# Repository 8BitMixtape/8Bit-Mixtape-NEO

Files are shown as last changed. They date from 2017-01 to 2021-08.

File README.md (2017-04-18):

# 8Bit Mixtape NEO
New Attiny85 based edition with Bootloader to program it via sound.

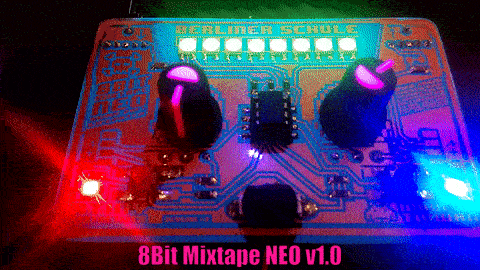
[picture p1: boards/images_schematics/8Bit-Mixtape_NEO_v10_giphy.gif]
Working v10_taipei


## Documentation and Instructions

It's all on the wiki...

## Arduino IDE-Integration

Add this to your additional hardware manager: http://8bitmixtape.github.io/package_8bitmixtape_index.json

See more on:  https://github.com/8BitMixtape/8Bit-Mixtape-NEO/wiki/4_3-IDE-integration

## Web-Interface

Upload examples directly from the browser: https://8bitmixtape.github.io/

Convert hex2Wav in browser and talk to your synth: https://8bitmixtape.github.io/8Bit-Mixtape-NEO/webpage/

## First Working prototypes

### Self-etched "Made in Taiwan"

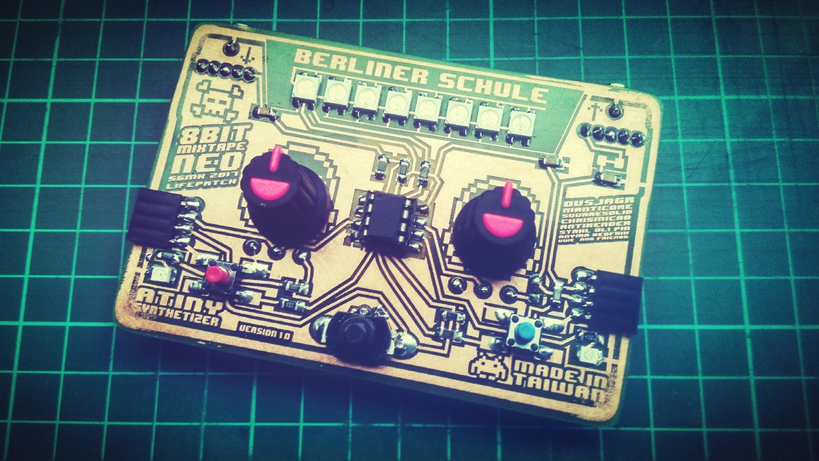
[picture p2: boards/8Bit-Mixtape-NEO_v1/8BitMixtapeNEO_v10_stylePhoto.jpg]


### Tokyo hand-solderer Prototype

See our first working prototype in the video: https://www.youtube.com/watch?v=9HnzJeK31R8

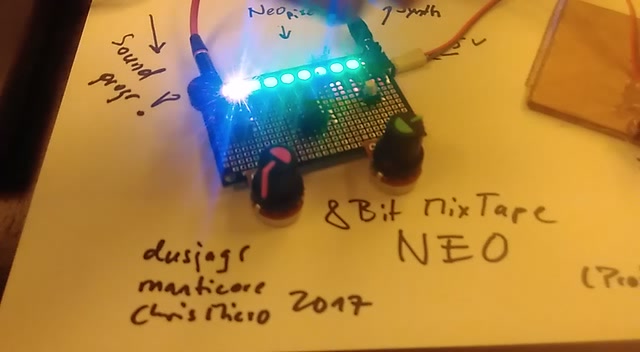
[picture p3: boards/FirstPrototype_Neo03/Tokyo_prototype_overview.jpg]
Working prototype_taipei


## Background
Inspired by the bootloader for atmega by Christoph Haberer and other implementations by Fredrik...
* http://www.hobby-roboter.de/forum/viewtopic.php?f=4&t=127
* http://www.fredrikolofsson.com/f0blog/?q=node%2F596

Not found anything yet for attiny, except that's it's a bit more challenging to make bootloaders.
* http://www.mikrocontroller.net/articles/Konzept_f%C3%BCr_einen_ATtiny-Bootloader_in_C

Can we maybe use the same bootloader to program via blinking lights?
* https://www.wayneandlayne.com/blinky_programmer/

# Bootloader developed and works fine
see devel repo here: 
* Iyoks devel: https://github.com/ATtinyTeenageRiot/TinyAudioBoot
* forked and improved by Chris: https://github.com/ChrisMicro/TinyAudioBoot
* find all files, pre-compiled and examples by Chris: https://github.com/ChrisMicro/AttinySound

# Boards are being designed atm...



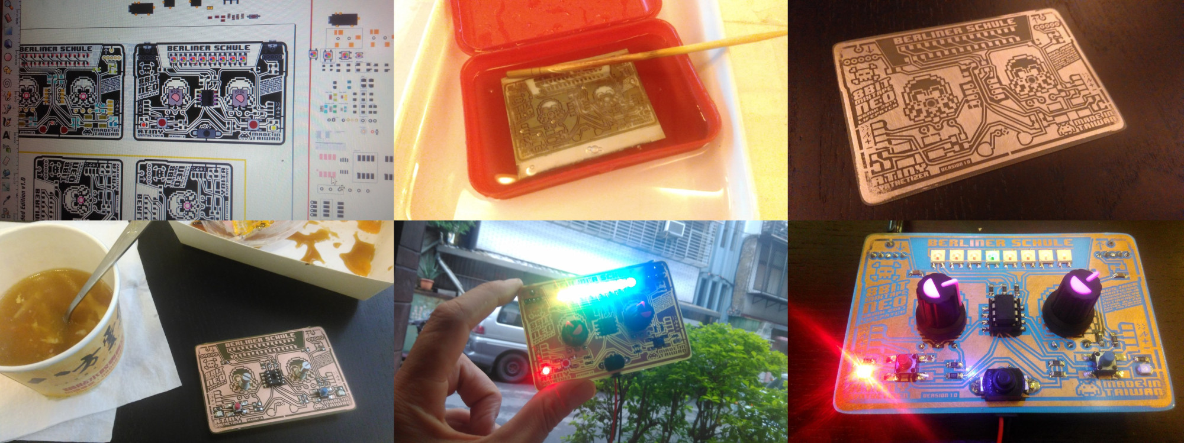
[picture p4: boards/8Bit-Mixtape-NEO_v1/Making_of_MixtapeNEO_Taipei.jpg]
Making board in Taipei


Making board in yogya

See more boards on the wiki: https://github.com/8BitMixtape/8Bit-Mixtape-NEO/wiki/2-Boards

# Test your prototype

Notes from our first testing phase: https://github.com/8BitMixtape/8Bit-Mixtape-NEO/wiki/3_5-Testing-the-prototypes

## Version 1.0

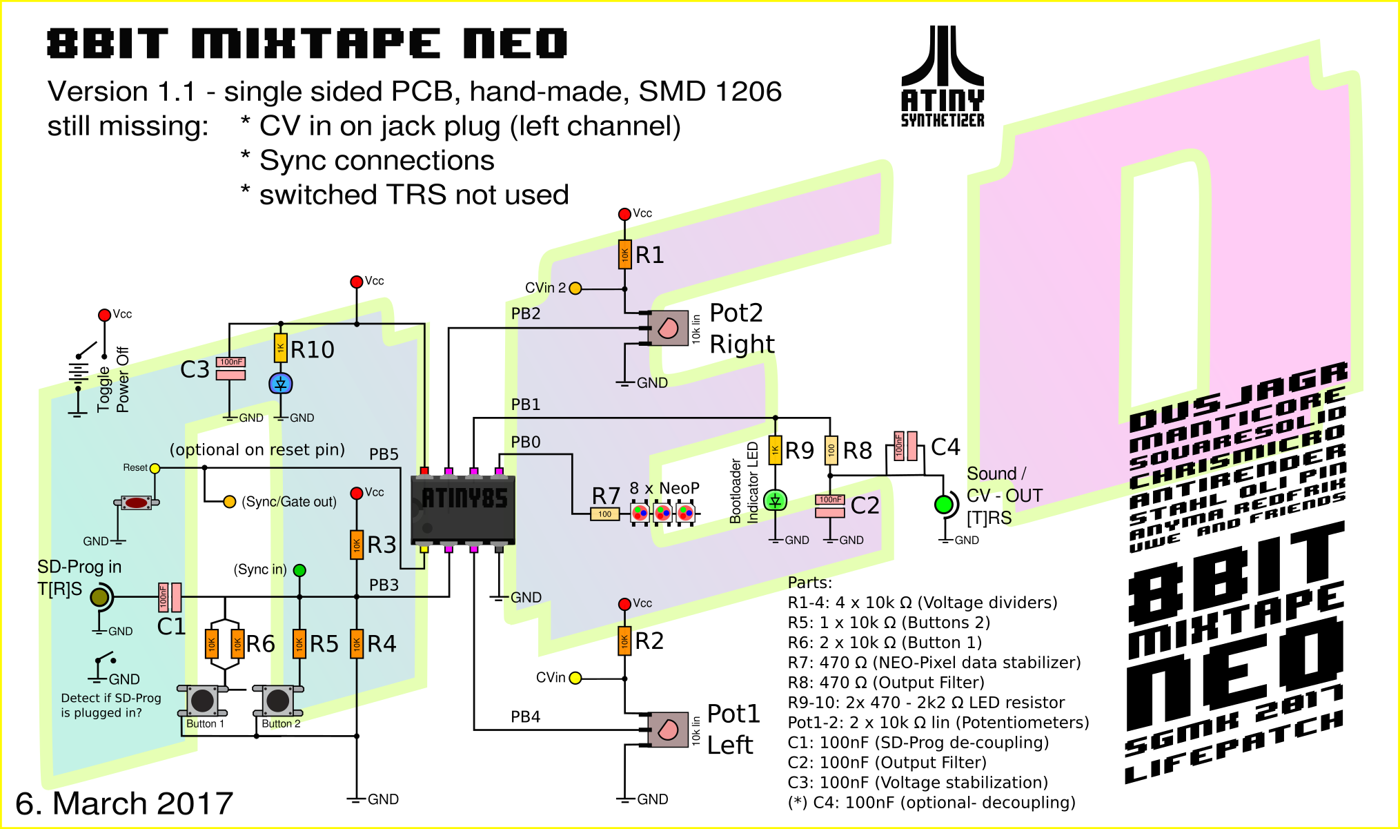
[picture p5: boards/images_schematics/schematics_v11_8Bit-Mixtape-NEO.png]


## Older versions

See wiki: https://github.com/8BitMixtape/8Bit-Mixtape-NEO/wiki/3_2-Schematics-Discussion

# Basic stuff we have

* 2 potentiometers
* 2 push-buttons
* 1 Sound output PWM (PB1 is preferred) is also CV output in case of Sequencer code
* Sound-progger input
* CV input (maybe 2 CV input
* Master-clock or gate output
* Sync-clock input (compatible to other voltages
* 1 pin to communicate wiht the 8 NEO-pixels (is that cheating?)
* what else? 
* mic-4 ring jacks?

# The Beginning...

Late night geeking at Iyok's ego-lab...

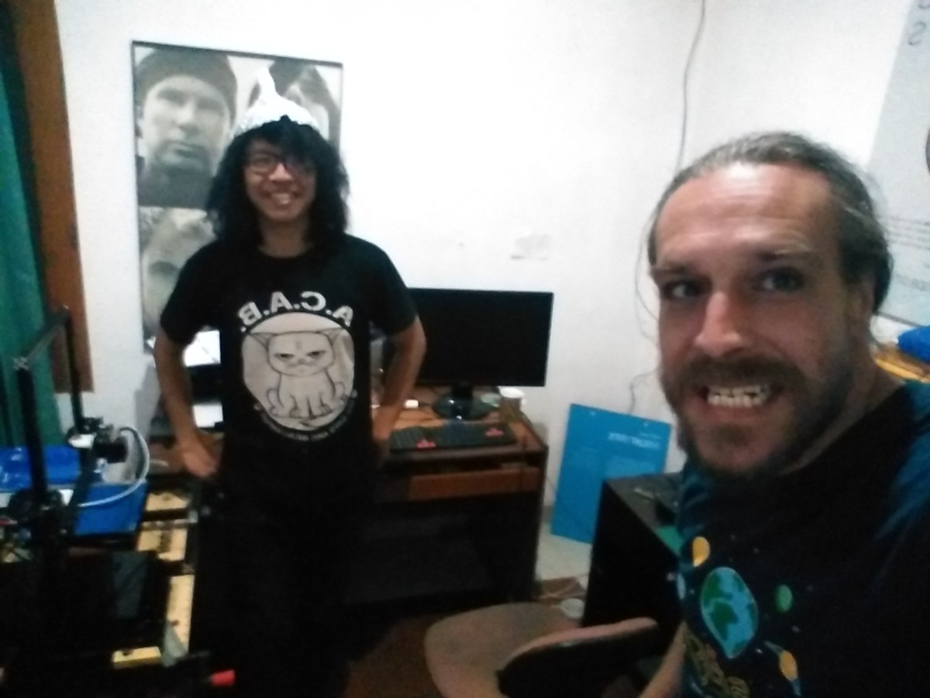
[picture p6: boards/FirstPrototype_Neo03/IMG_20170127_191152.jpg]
Late night geeking at Iyok's ego-lab


After years of geeking around wiht all these versions of 8bit Mixtapes...

[http://lifepatch.org/8-bit_Mixtape](http://lifepatch.org/8-bit_Mixtape)

or 

[http://wiki.sgmk-ssam.ch/wiki/8bit_Mix_Tape](http://wiki.sgmk-ssam.ch/wiki/8bit_Mix_Tape)

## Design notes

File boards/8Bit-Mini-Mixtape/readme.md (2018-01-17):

#### Joining the 8Bit Mixtape Madness!!  

Discussion group on all kinda codes, soundzz and new developments for the 8Bit-Mixtape.  

Follow on github:
[8Bit Mixtape github](https://github.com/8BitMixtape)  

and more documentation on the SGMK wiki:
[8Bit Mixtape wiki](http://wiki.sgmk-ssam.ch/wiki/8bit_Mix_Tape)

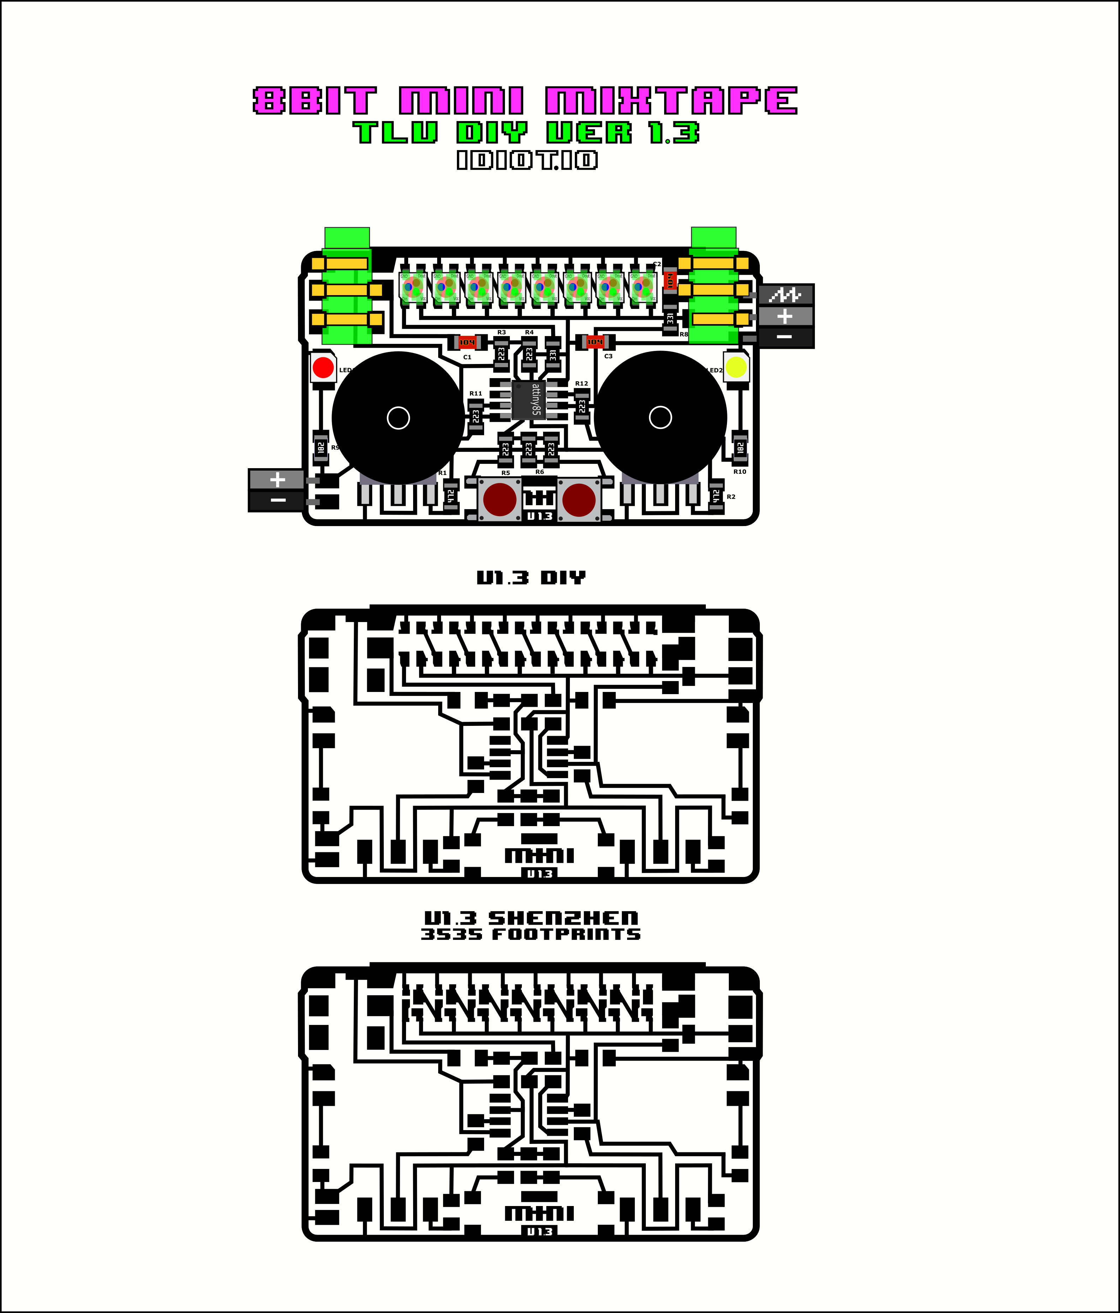
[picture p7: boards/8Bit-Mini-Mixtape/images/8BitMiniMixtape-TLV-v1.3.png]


[svg file](8BitMiniMixtape-TLV.svg)

##### PCB Layout Design
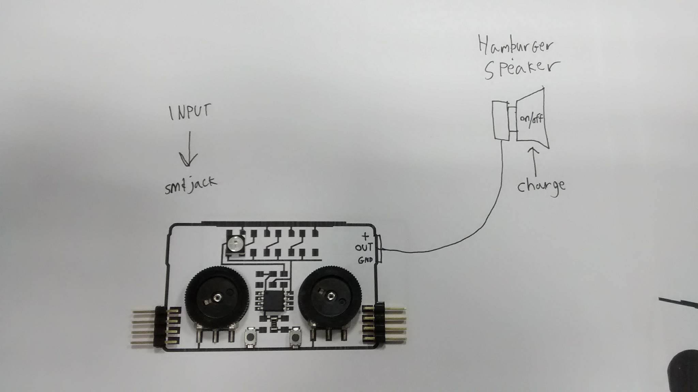
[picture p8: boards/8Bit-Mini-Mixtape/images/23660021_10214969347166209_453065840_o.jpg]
  
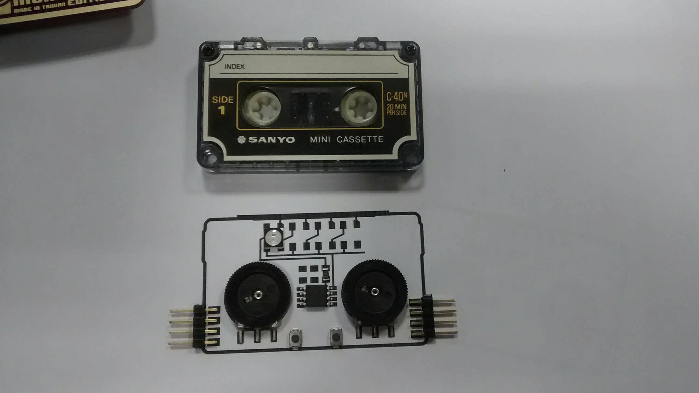
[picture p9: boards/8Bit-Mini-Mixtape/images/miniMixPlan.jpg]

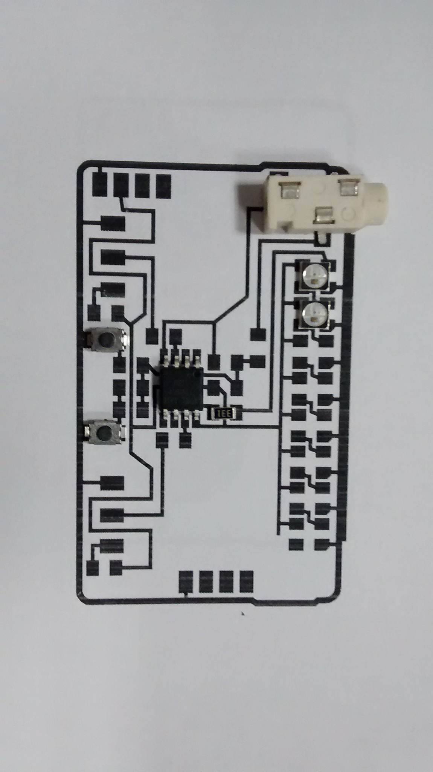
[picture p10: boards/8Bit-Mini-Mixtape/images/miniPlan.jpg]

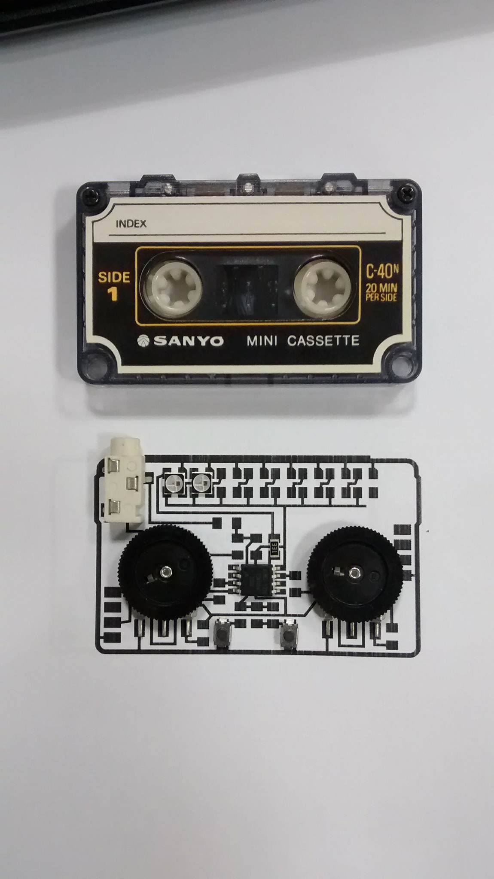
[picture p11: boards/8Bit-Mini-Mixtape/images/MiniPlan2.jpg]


##### Flexible PCB Photolithography Process Using Photoresist Dry Film & Pyralux
UV Exposure 1:45 Min  

Soudium Carbonate 2g:200ml water  

video soon...

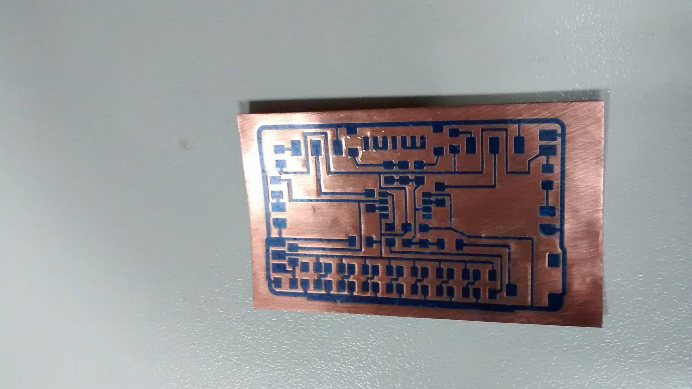
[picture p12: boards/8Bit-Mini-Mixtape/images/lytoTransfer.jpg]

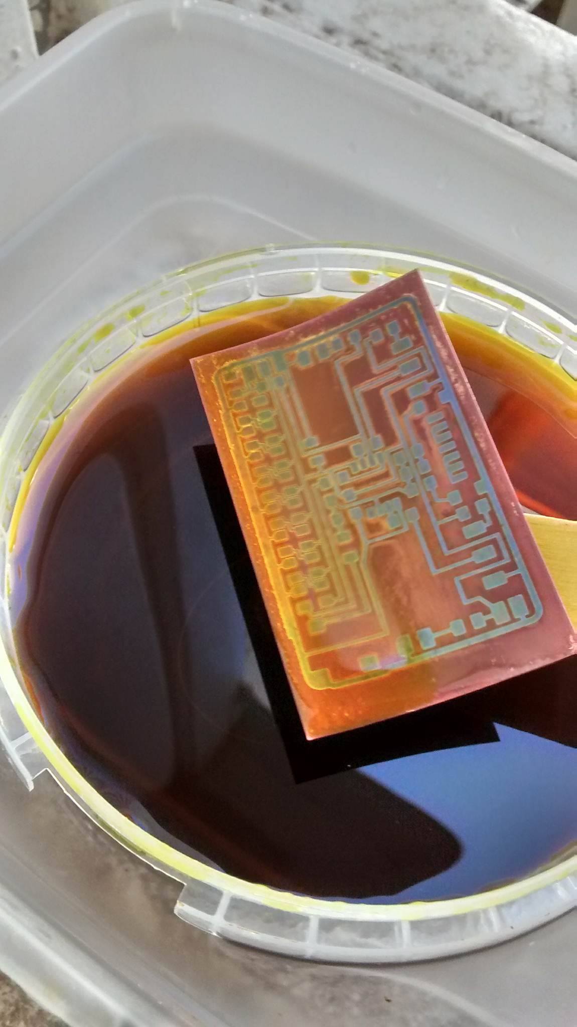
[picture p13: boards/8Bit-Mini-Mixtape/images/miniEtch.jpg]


##### Etching Using Ferric chloride
ferric 1:1 water  

(we Should Ditch the ferric and switch to NaPS approx 200-300g per liter water at 50C)

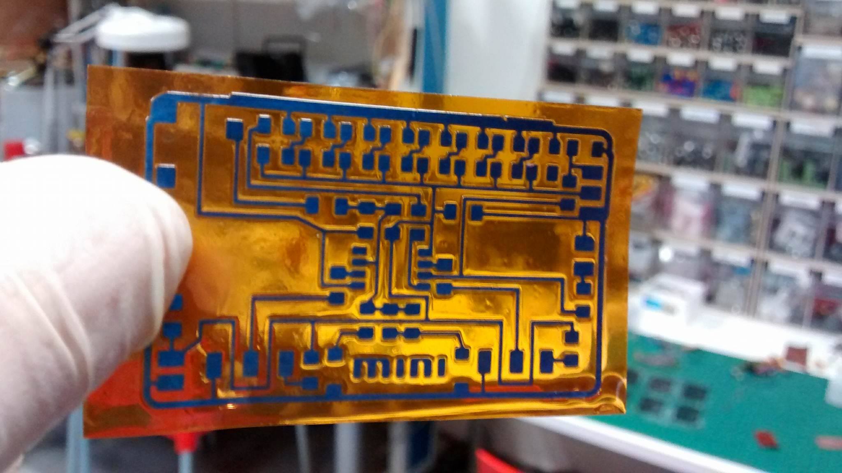
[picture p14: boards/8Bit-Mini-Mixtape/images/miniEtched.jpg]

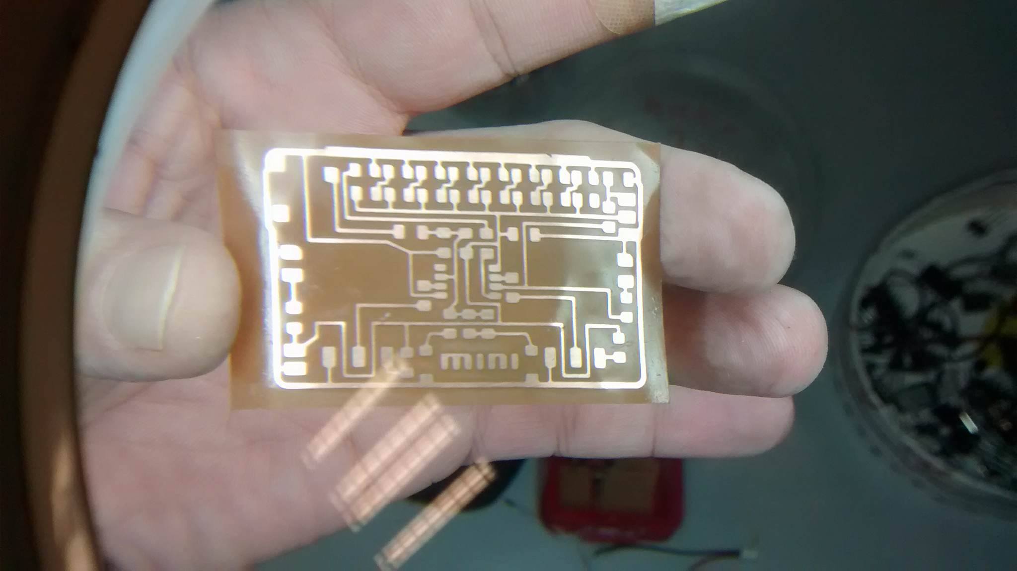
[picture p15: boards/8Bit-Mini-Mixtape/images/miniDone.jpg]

* Made Few design mistakes with 3535 LEDS Pads... fixed now!!

##### First working Mini Mixtape Test! on FR4 Clad
Etched With NaPS & Assembled by The 8Bit Mixtape Guru Master Marc Dusseiller Dusjagr!!!

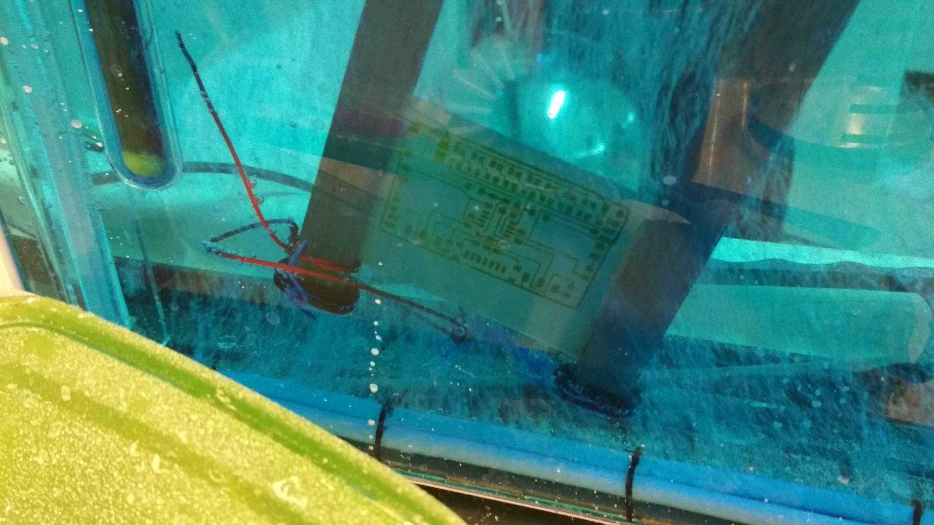
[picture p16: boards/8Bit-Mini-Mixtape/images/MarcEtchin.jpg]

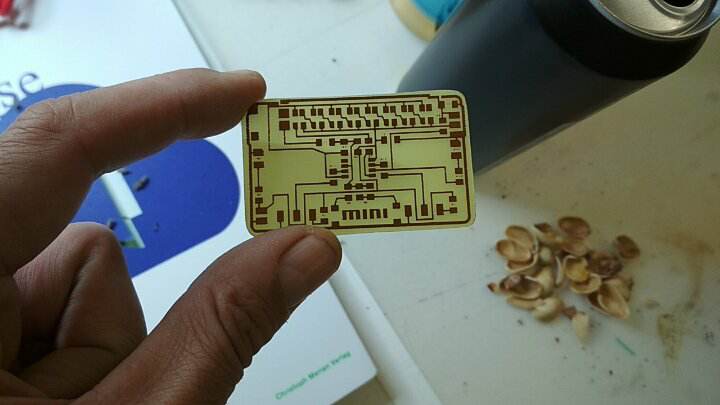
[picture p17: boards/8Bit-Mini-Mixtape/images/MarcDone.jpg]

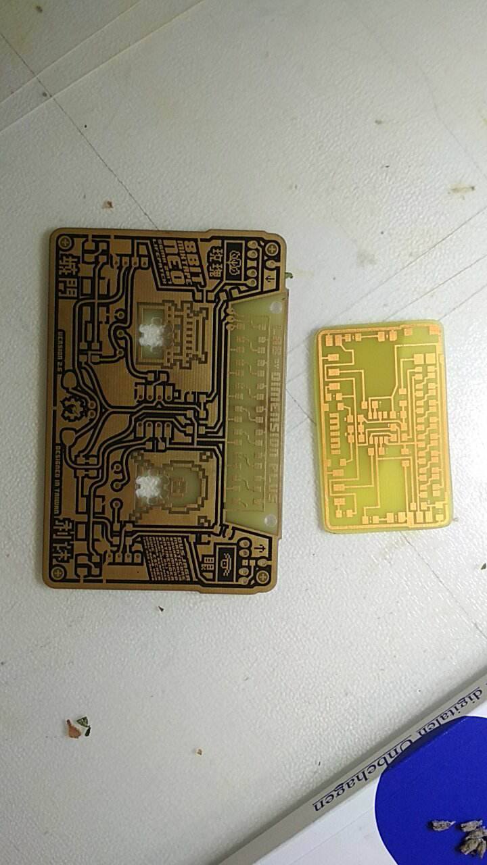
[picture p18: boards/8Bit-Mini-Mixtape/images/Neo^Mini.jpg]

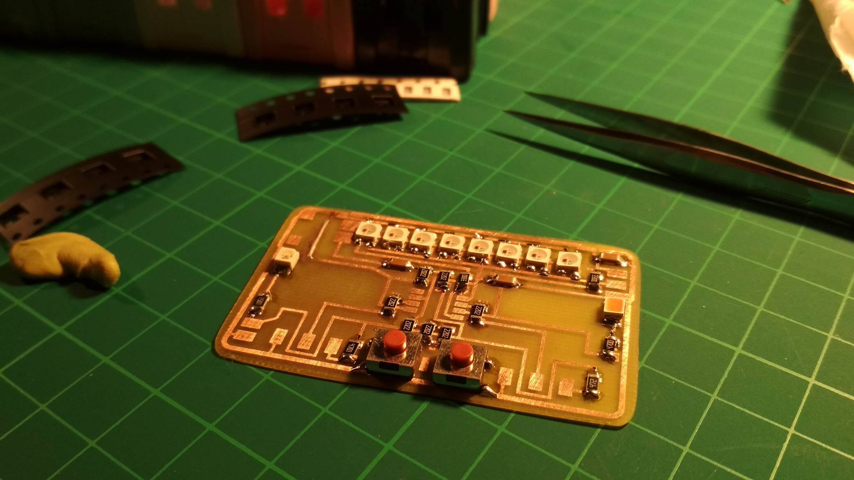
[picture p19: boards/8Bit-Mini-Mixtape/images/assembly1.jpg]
![
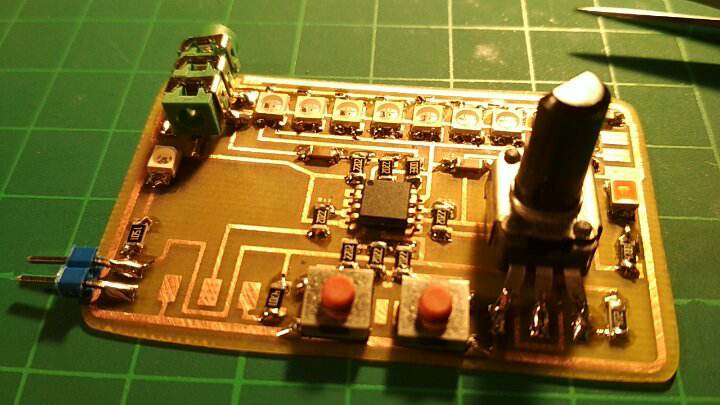
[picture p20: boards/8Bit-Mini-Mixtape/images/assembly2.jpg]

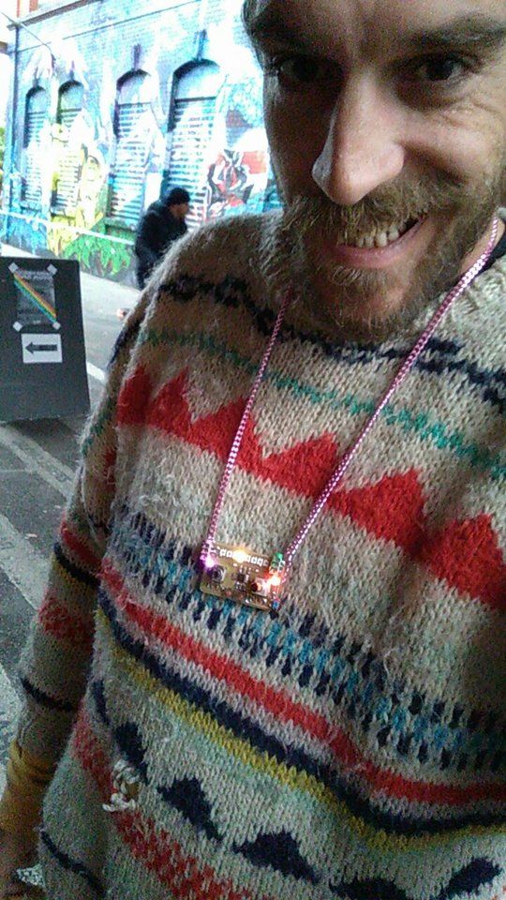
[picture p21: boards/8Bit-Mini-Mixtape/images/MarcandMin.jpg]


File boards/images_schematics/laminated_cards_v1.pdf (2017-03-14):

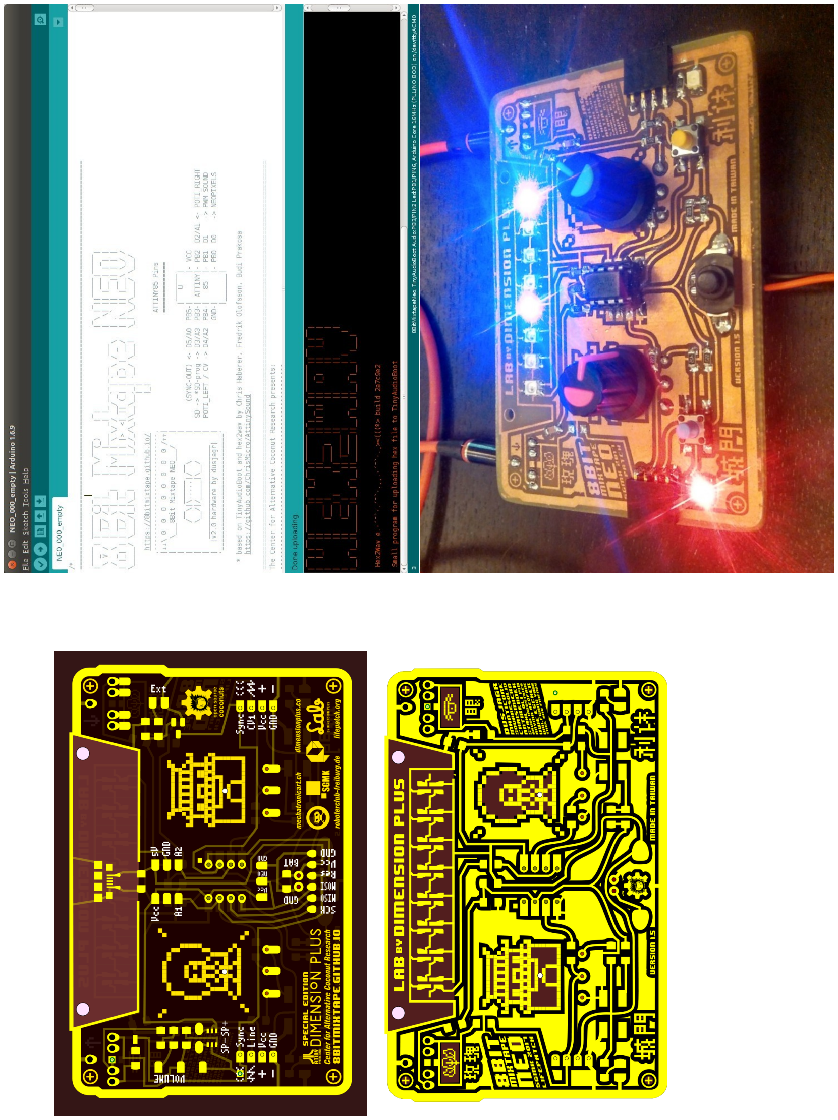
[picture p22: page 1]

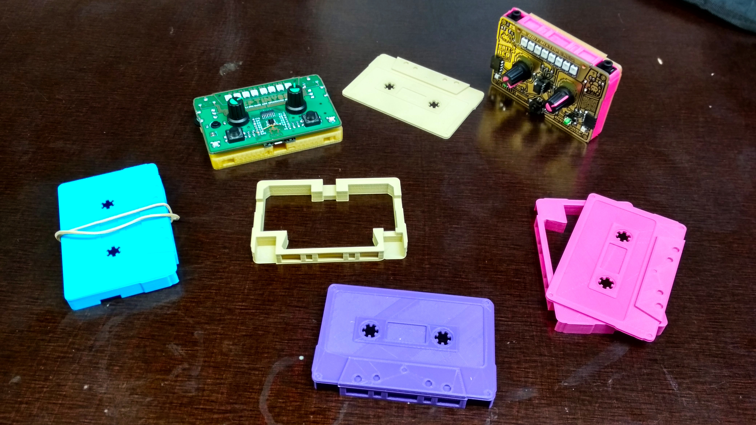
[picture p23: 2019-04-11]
boards/3d-files/Photos/3D-cases_Overview.jpg

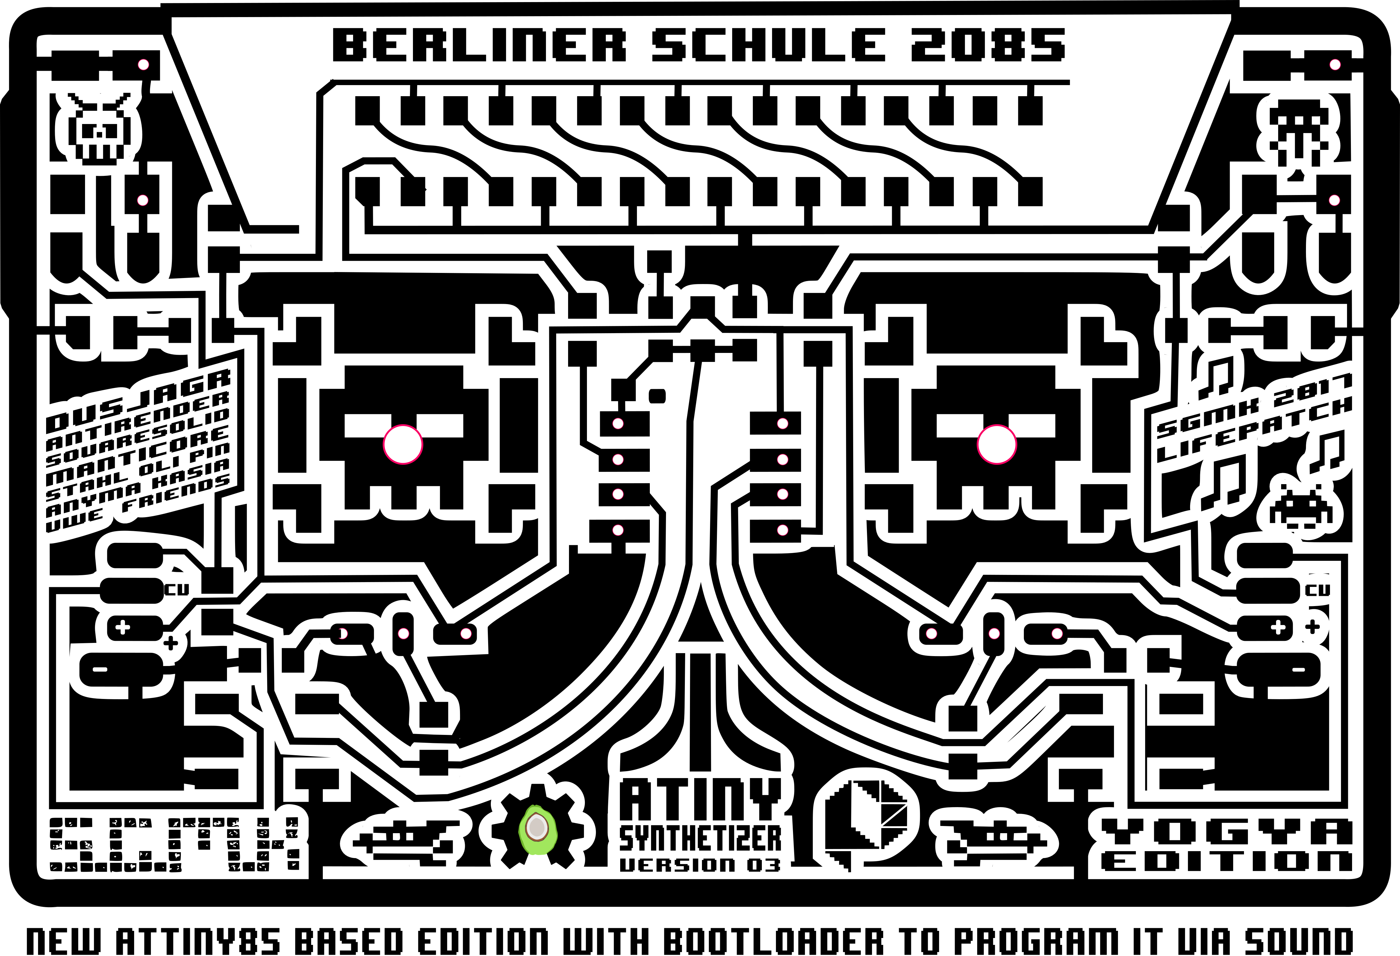
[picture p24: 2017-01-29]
boards/images_schematics/85SoundProg_MixTape_V03-NEO_high.png

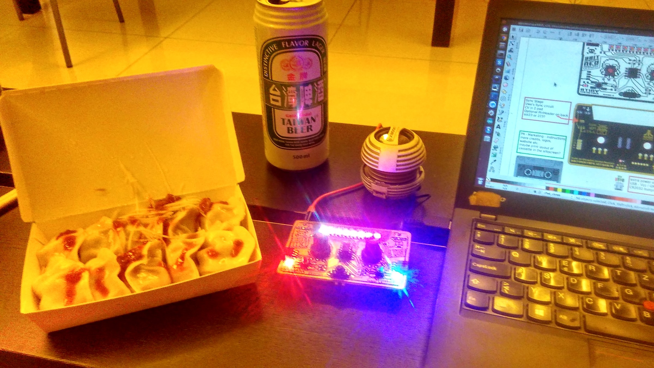
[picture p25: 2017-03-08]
boards/images_schematics/lateNight_boardDesigns.jpg

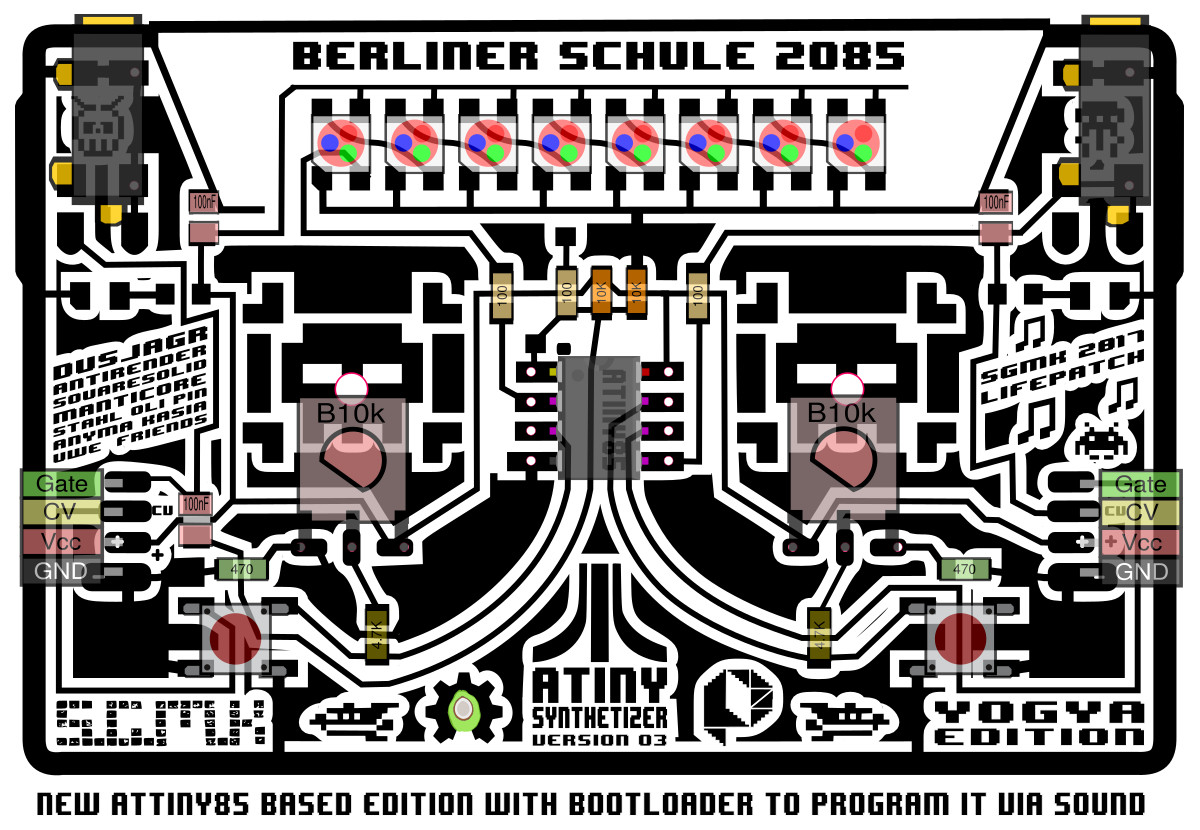
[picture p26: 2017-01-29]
boards/images_schematics/85SoundProg_MixTape_V03-NEO.jpg

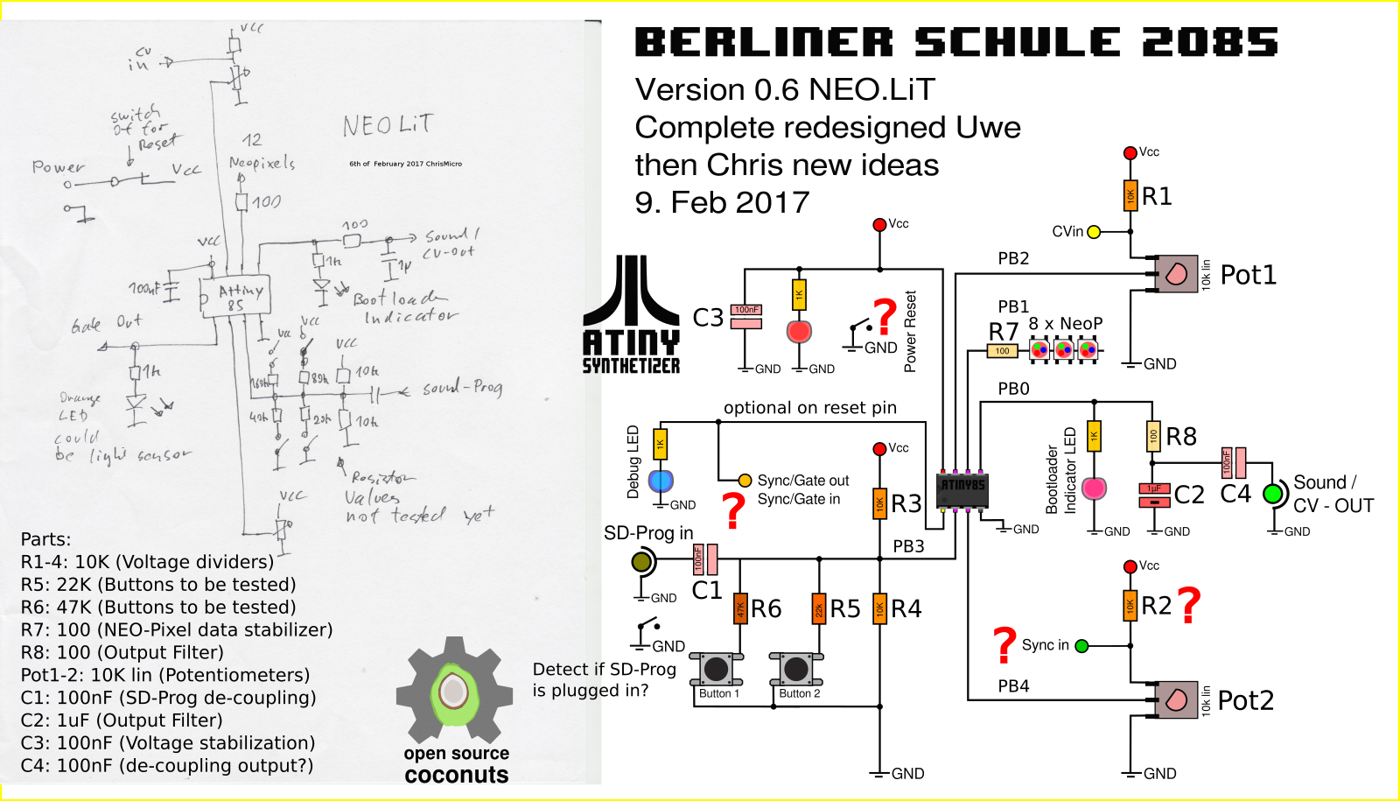
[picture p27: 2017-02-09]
boards/images_schematics/Schematics_85SoundProg_MixTape_V07.png

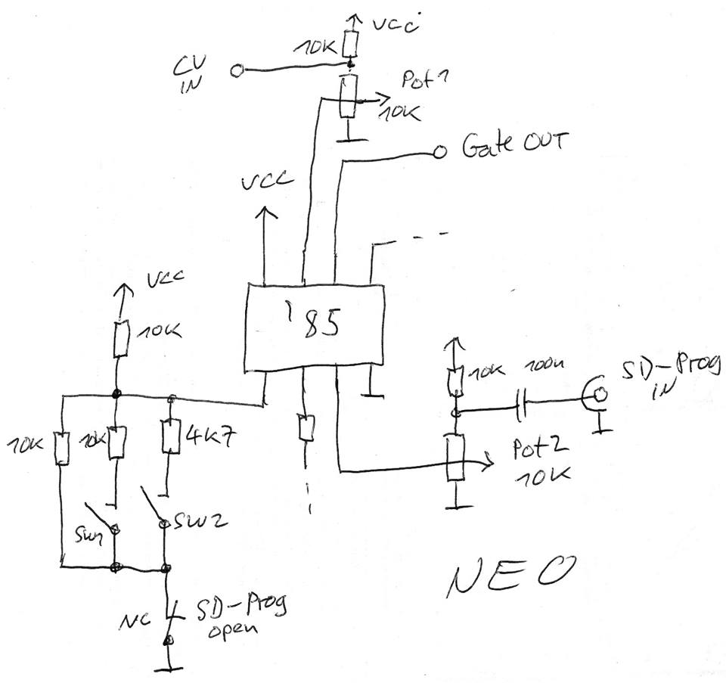
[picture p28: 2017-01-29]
boards/images_schematics/Uwe_schematics_tip.jpg

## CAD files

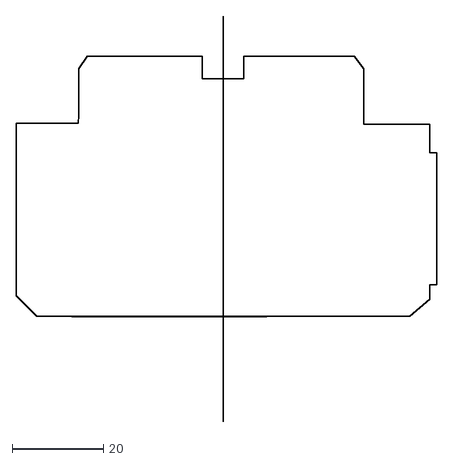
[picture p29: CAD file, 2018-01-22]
boards/8Bit-NEO-Casing-Manticore-Build/mixtape_case_3D_MainCase.dxf
91.9 x 88.7

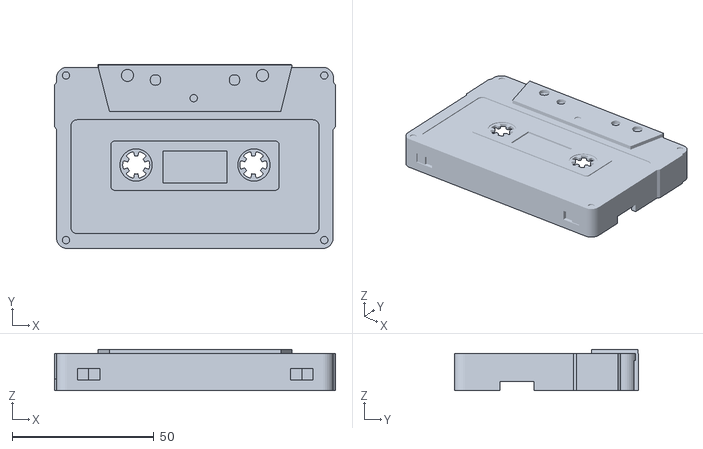
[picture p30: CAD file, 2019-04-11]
boards/3d-files/MixTape_FullCase_VerApril19_10.stl
99.0 x 64.8 x 14.6

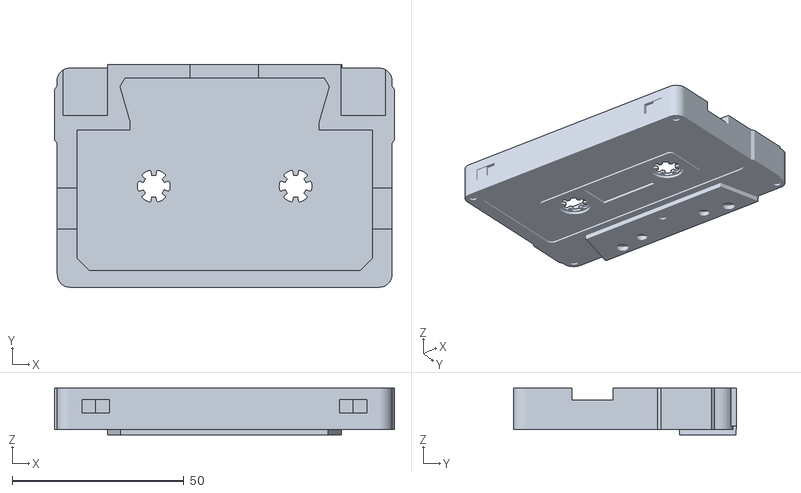
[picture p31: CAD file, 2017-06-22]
boards/8Bit-NEO-Casing-Manticore-Build/3D_mixTape_FullCase_USB2.stl
99.0 x 64.8 x 13.6

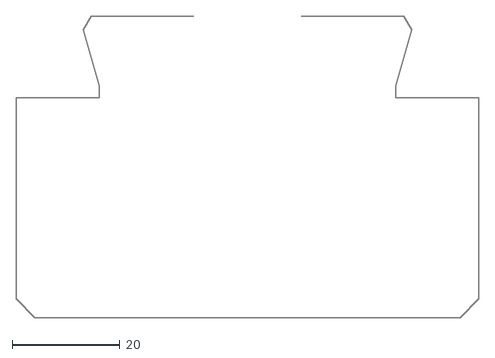
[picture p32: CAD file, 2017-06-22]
boards/8Bit-NEO-Casing-Manticore-Build/mixtape_case_3D_MainCase_USB.dxf
86.0 x 56.0

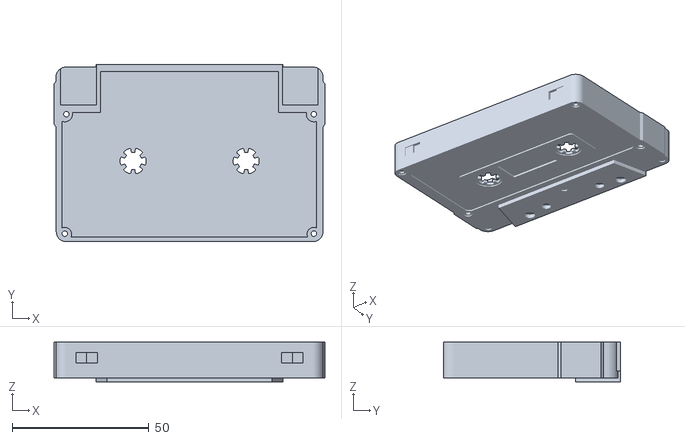
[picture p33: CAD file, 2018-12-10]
boards/3d-files/3D_MixTape_FullCase_VerDez18_03.stl
99.0 x 64.8 x 14.6

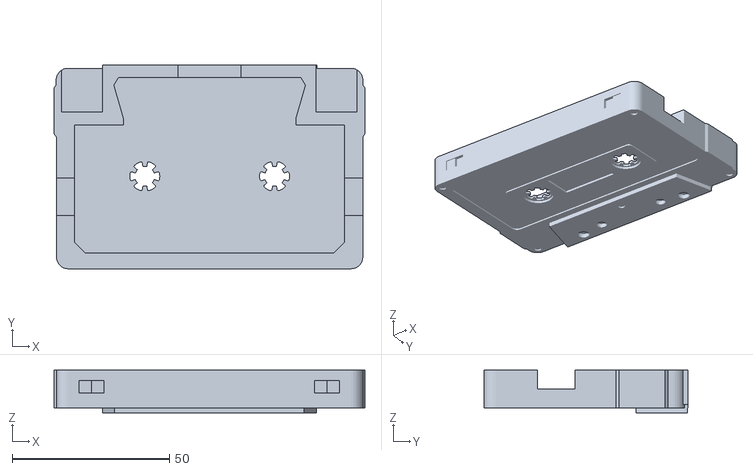
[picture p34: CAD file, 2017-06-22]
boards/8Bit-NEO-Casing-Manticore-Build/3D_mixTape_FullCase_USB.stl
99.0 x 64.8 x 13.6

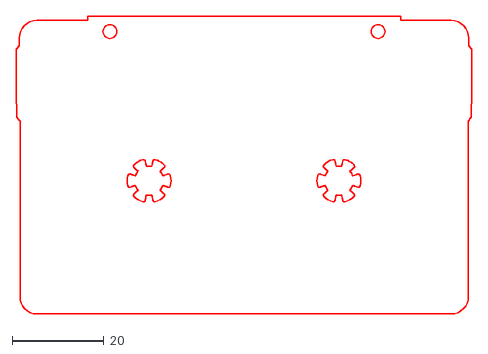
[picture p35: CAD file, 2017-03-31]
boards/8Bit-Mixtape-NEO_v1/TaiwanReady/8BitMixtape_NEO_v20_cuts.dxf
99.0 x 64.8

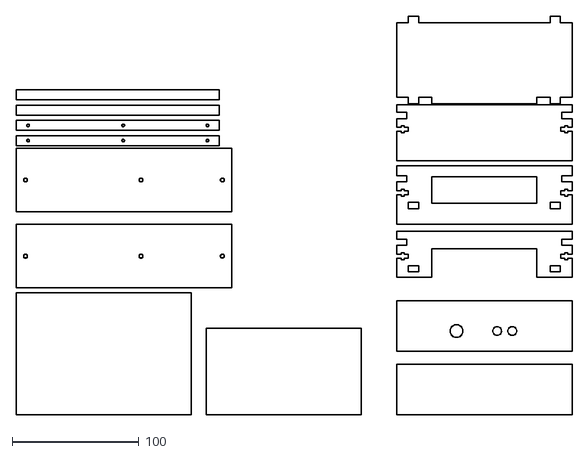
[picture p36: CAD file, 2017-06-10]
boards/DIMI-8/DIMI_chistli_anyma_12_jana.dxf
438.0 x 314.0

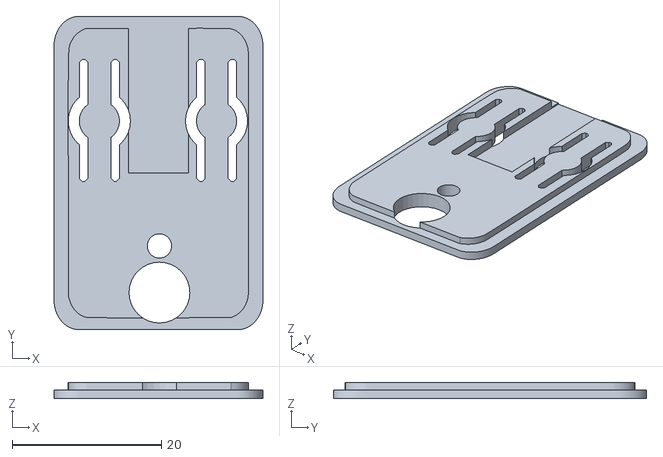
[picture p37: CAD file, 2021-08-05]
boards/3d-files/FlexiTiny_Case.stl
28.0 x 42.0 x 2.20

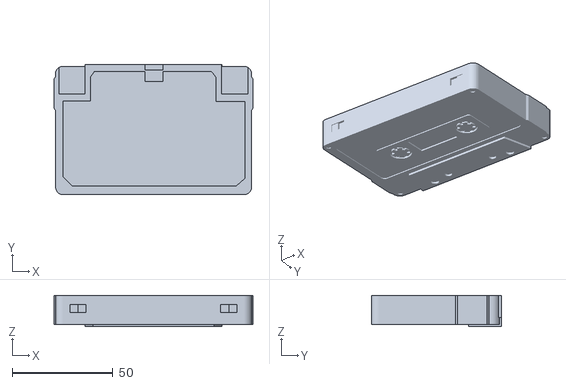
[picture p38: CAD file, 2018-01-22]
boards/8Bit-NEO-Casing-Manticore-Build/3D_mixTape_Rahmli.stl
99.0 x 64.8 x 15.6

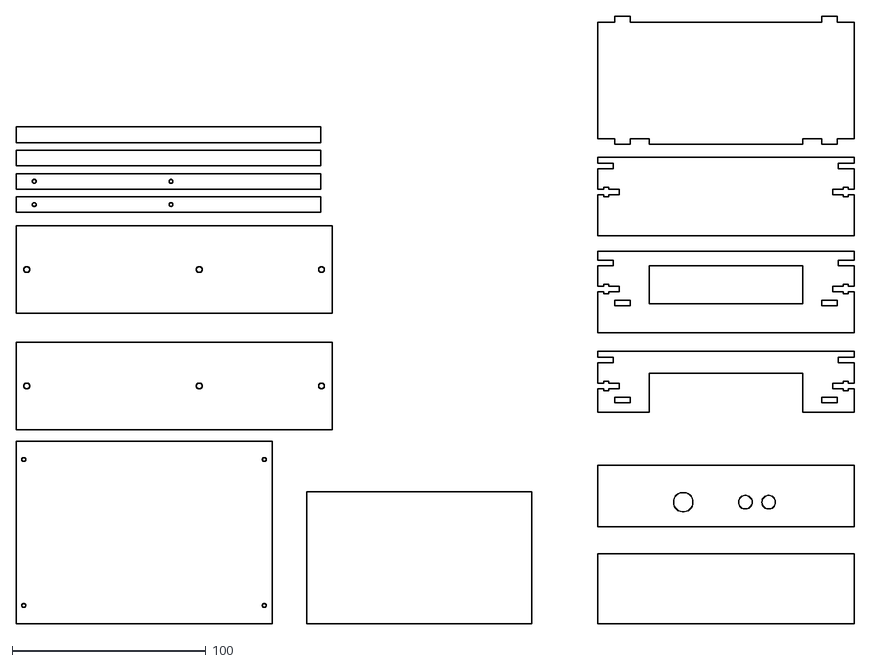
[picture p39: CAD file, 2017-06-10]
boards/DIMI-8/DIMI_chistli_anyma_10.dxf
432.0 x 313.0

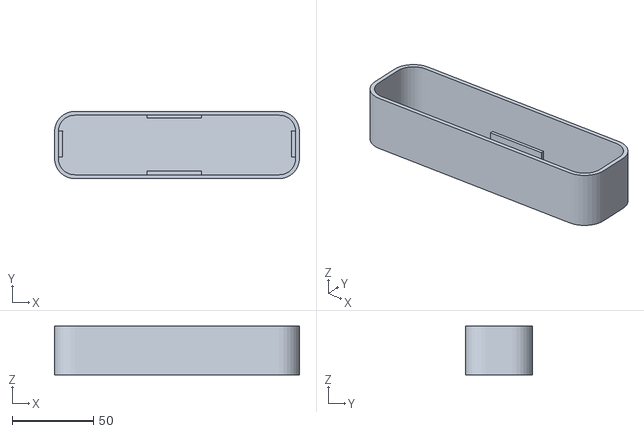
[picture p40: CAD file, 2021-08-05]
boards/3d-files/BlinkeShit_Case.stl
150.6 x 41.4 x 30.0

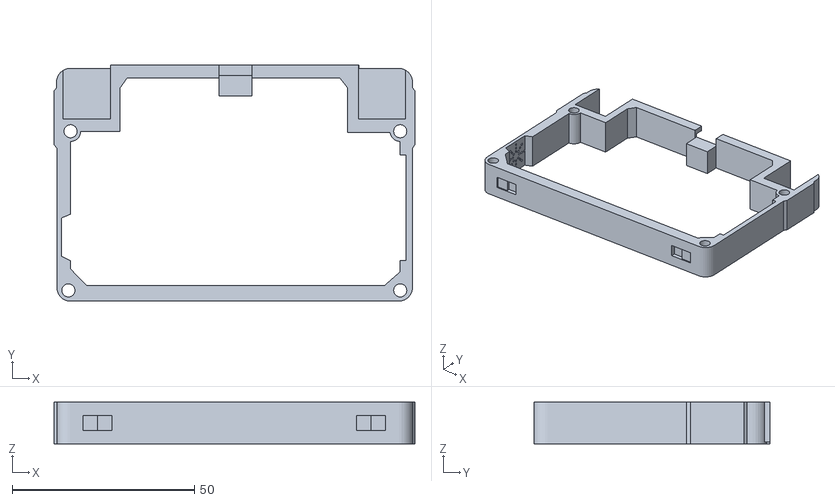
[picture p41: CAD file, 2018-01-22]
boards/8Bit-NEO-Casing-Manticore-Build/3D_mixTape_Rahmli bottom.stl
99.0 x 64.8 x 11.5

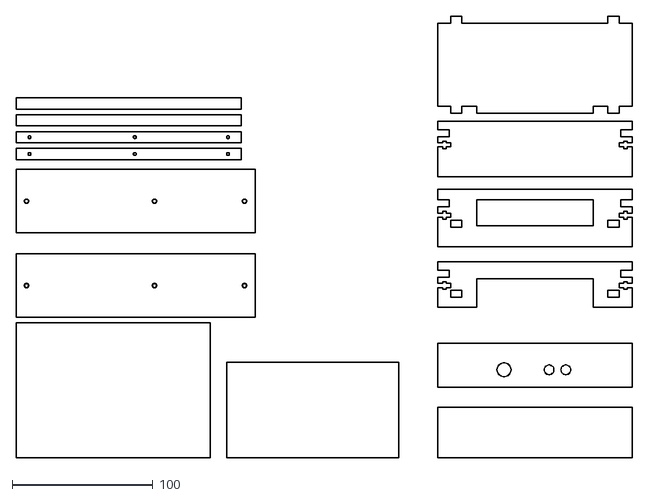
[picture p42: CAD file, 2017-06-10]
boards/DIMI-8/DIMI_chistli_anyma_11.dxf
438.0 x 314.0

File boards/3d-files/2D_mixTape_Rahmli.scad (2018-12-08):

////// MixTape 3d Printed Case///////////////////////////

// 

plugHeight = 9.8; // [6:10]
tapeHeight = 11.5; //
topThickness = 1.6; 

bottom_wall_thickness = 2;

usb_charger = false;
cutout_aux_ports = false;

//rotate([55,0,$t*380]) translate([-50,0,0]){
rotate([0,0,0]) translate([0,0,0]){
PCB();
parts();

difference(){
    
    union(){
        tapeBody();
        tapeTop();
    }
    
    // Plugs 
    translate([2.5,50,tapeHeight-plugHeight+topThickness]) cube([13,20,plugHeight+1],false); 
    translate([83.5,50,tapeHeight-plugHeight+topThickness]) cube([13,20,plugHeight+1],false);
    
    // write protectors 
    translate([10,0,0.5*tapeHeight+1.6]) cube([4,1,4],true);
    translate([13.9,0,0.5*tapeHeight+1.6]) cube([4,3,4],true);
    translate([89,0,0.5*tapeHeight+1.6]) cube([4,1,4],true);
    translate([85.1,0,0.5*tapeHeight+1.6]) cube([4,3,4],true);

    // Power signs
    //if (!usb_charger) {
    //    translate([41,0,0.5*tapeHeight+1.6]) cube([4,1.5,1],true);
    //    translate([41,0,0.5*tapeHeight+1.6]) cube([1,1.5,4],true);
    
    //    translate([58,0,0.5*tapeHeight+1.6]) cube([4,1.5,1],true); 
    //}
}
}

module FullCase(){
    tapeBody();
    tapeTop();
}


// Modules ///////////////////////////////

module PCB(){
color("DarkKhaki") 
translate ([0,0,tapeHeight+1.6]) linear_extrude(height = 1.6, center = false, convexity = 10, twist = 0) import("mixtape_case_3D_bottom.dxf", convexity=3);
color("Gold") 
translate ([0,0,tapeHeight+3.2]) linear_extrude(height = 0.2, center = false, convexity = 10, twist = 0) import("mixtape_case_3D_PCB.dxf", convexity=3);

color("DarkKhaki") 
translate ([0,0,tapeHeight+2*topThickness]) linear_extrude(height = 1.6, center = false, convexity = 10, twist = 0) import("mixtape_case_3D_PCB_TrapezBoard.dxf", convexity=3);
color("Gold") 
translate ([0,0,tapeHeight+3*topThickness]) linear_extrude(height = 0.2, center = false, convexity = 10, twist = 0) import("mixtape_case_3D_PCB_TrapezCircuit.dxf", convexity=3);
}

module tapeBody(){ 
    difference(){
        union(){
            difference(){ 
                //color("Deeppink") 
                translate ([0,0,1.6]) linear_extrude(height = tapeHeight, center = false, convexity = 10, twist = 0) import("mixtape_case_3D_bottom.dxf", convexity=3);  

                //if (!usb_charger) {
                    //translate ([0,0,0.6]) linear_extrude(height = tapeHeight+4, center = false, convexity = 10, twist = 0) import("mixtape_case_3D_MainCase.dxf", convexity=3);
                //} else {
                    //translate ([0,0,0.6]) linear_extrude(height = tapeHeight+4, center = false, convexity = 10, twist = 0) import("mixtape_case_3D_MainCase_USB.dxf", convexity=3);
                //}
      
                //Face holes
                translate([25,64,0.5*tapeHeight+topThickness]) cube([12,4,0.7*tapeHeight],true);
                if (!usb_charger) { 
                    translate([49.5,64,0.5*tapeHeight+topThickness]) cube([16,4,0.7*tapeHeight],true); 
                }
                translate([74.3,64,0.5*tapeHeight+topThickness]) cube([12,4,0.7*tapeHeight],true);

                translate([36,65,0.5*tapeHeight+topThickness]) cube([4,4,0.7*tapeHeight],true);
                translate([63,65,0.5*tapeHeight+topThickness]) cube([4,4,0.7*tapeHeight],true);

                if (usb_charger) {
                    // cutout usb port
                    translate([49.5,64,0.5*tapeHeight+topThickness+3])cube([20,14,0.7*tapeHeight+4],true);
                }


                if (cutout_aux_ports) {
                    translate([1.5,23,0.5*tapeHeight+topThickness+3]) cube([20,12,tapeHeight],true);
                    translate([90,23,0.5*tapeHeight+topThickness+3]) cube([20,12,tapeHeight],true);      
                }
            }
            translate([49.5,7.05,0.5*tapeHeight+topThickness]) cube([90,14,1*tapeHeight],true);
        } //end union
        // wall thickness
        translate([49.5,22.5+bottom_wall_thickness,0.5*tapeHeight+topThickness-1]) cube([90,45,1*tapeHeight+7],true);
        translate([49.5,40+bottom_wall_thickness,0.5*tapeHeight+topThickness-1]) cube([65,35,0.7*tapeHeight+7],true);
    } // end difference
    //color("DarkKhaki") 
    if (!usb_charger) {
    //translate([40,0.05,1.6]) cube([20,10,2.5],false);
    }
}

module tapeTop(){ 
 
difference(){ 
 color("Deeppink") 
     translate ([0,0,-1.5]) linear_extrude(height = 1.5, center = false, convexity = 10, twist = 0) import("mixtape_case_3D_TopTrapez.dxf", convexity=3);
     
   color("Gold") 
     translate ([0,0,-2.2]) linear_extrude(height = 3, center = false, convexity = 10, twist = 0) import("mixtape_case_3D_Holes.dxf", convexity=3);
   translate([50,53,-2.2]) cylinder(h=1.2, r=1.3, center=false, ,$fn=30);
}   
    

difference(){    
  color("Deeppink") 
     translate ([0,0,0]) linear_extrude(height = 1.6, center = false, convexity = 10, twist = 0) import("mixtape_case_3D_bottom.dxf", convexity=3);

  translate([4,3,-1]) cylinder(h=1.5, r=1.3, center=false, ,$fn=30);
  translate([95,3,-1]) cylinder(h=1.5, r=1.3, center=false, ,$fn=30);
  translate([4,61,-1]) cylinder(h=1.5, r=1.3, center=false, ,$fn=30);
  translate([95,61,-1]) cylinder(h=1.5, r=1.3, center=false, ,$fn=30);
    
  color("Pink") 
     translate ([0,0,-1.3]) linear_extrude(height = 2, center = false, convexity = 10, twist = 0) import("mixtape_case_3D_WindowRect.dxf", convexity=3); 
    
  difference(){    
  color("Gold") 
     translate ([0,0,-0.5]) linear_extrude(height = 1, center = false, convexity = 10, twist = 0) import("mixtape_case_3D_BigRect.dxf", convexity=3);  
  

  translate ([0,0,-3]) linear_extrude(height = 10, center = false, convexity = 10, twist = 0) import("mixtape_case_3D_MidRect.dxf", convexity=3);   
  }
  
  translate ([0,0,-3]) linear_extrude(height = 5.5, center = false, convexity = 10, twist = 0) import("mixtape_case_3D_Wheels.dxf", convexity=3); 
}

  translate ([0,0,0.4]) linear_extrude(height = 1.2, center = false, convexity = 10, twist = 0) import("mixtape_case_3D_NutWheels.dxf", convexity=3); 

}
 

module parts(){
    // IC-Socket
  color("Grey")
      translate([44,22.5,tapeHeight+2*topThickness]) cube([11,13,4],false);
    
  difference(){
  color("Black")
      translate([45,23.5,tapeHeight+2*topThickness]) cube([9,11,7],false);
        
    translate([49.5,34.5,tapeHeight+2*topThickness+6]) cylinder(h=10, r=1.5, center=false, ,$fn=30);
    }
    
    // NEO-Pixels
    for (a = [ 0 : 6.3 : 46 ])
    translate([a,0,0]) NEOpixel();
    
    module NEOpixel(){
    color("White")
      translate([25.2,52.5,tapeHeight+3*topThickness]) cube([5,5,2],false);
        
    color("Deeppink")
      translate([27.7,55,tapeHeight+3*topThickness]) cylinder(h=2.5, r=2, center=false, ,$fn=30);
    }
    
    // Pots
    potentiometer();
    translate ([42,0,0]) potentiometer();
    
    module potentiometer(){
    color("Grey")
      translate([29,29,tapeHeight+2*topThickness]) cylinder(h=10, r=3.5, center=false, ,$fn=30);
    
    color("Deeppink")
        translate([29,29,tapeHeight+2*topThickness+2]) cylinder(h=12, r1=6, r2=4.5, center=false, ,$fn=30);
    }
    
    // Buttons
    button();
    translate ([58,0,0]) button();
    
    module button(){
    color("Grey")
      translate([17.5,9.8,tapeHeight+2*topThickness]) cube([6,6,3],false);
        
    color("Red")
      translate([20.5,12.8,tapeHeight+2*topThickness]) cylinder(h=5, r=1.5, center=false, ,$fn=30);
    }

}

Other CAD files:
boards/8Bit-NEO-Casing-Manticore-Build/3D_mixTape_FullCase_v04_100.stl
boards/3d-files/MixTape_Case_VerMayl19_11.stl
boards/3d-files/MixTape_Case_VerMar19_05.stl
boards/8Bit-NEO-Casing-Manticore-Build/3D_mixTape_Rahmli top.stl
boards/3d-files/2D_mixTape_Rahmli_bat.scad
boards/3d-files/3D_mixTape_Rahmli_v10.scad
boards/3d-files/3D_mixTape_Rahmli_v11_batterieAAA.scad
boards/3d-files/2D_mixTape_Rahmli_bat.stl
boards/3d-files/2D_mixTape_Rahmli_bat_thin.stl
boards/3d-files/2D_mixTape_deckel.stl
boards/3d-files/3D_MixTape_Cover_VerDez18_03.stl
boards/3d-files/3D_MixTape_Frame_VerDez18_03.stl
boards/3d-files/3D_mixTape_Rahmli_v05.scad
boards/3d-files/3D_mixTape_TOP.stl
boards/3d-files/FlexiTiny_Case.scad
boards/3d-files/MandiRanden.scad
boards/3d-files/MixTape_Case_VerApril19_10.scad
boards/3d-files/MixTape_Case_VerDez18_02.scad
boards/3d-files/MixTape_Case_VerDez18_03.scad
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

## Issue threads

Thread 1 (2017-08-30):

board package is offline

5shekel, 2017-08-30:
while adding the board def from the json file i get
``` Error downloading http://neo.manticore.id/package/8bitmixtape-0.0.20.tar.gz```

badgeek, 2017-08-30:
can you open http://neo.manticore.id/package/8bitmixtape-0.0.20.tar.gz

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

--
Budi Prakosa
e: iyok@deadmediafm.org | budi.prakosa@gmail.com
p: +62 811 268 995
w: manticore.deadmediafm.org | lifepatch.org

badgeek, 2017-08-30:
ok its fixed now.....

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

--
Budi Prakosa
e: iyok@deadmediafm.org | budi.prakosa@gmail.com
p: +62 811 268 995
w: manticore.deadmediafm.org | lifepatch.org

Closed 2017-08-30.

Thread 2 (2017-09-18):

Mixtape NEO V1 resistors

morriswinkler, 2017-09-18:
Hello,

I got a couple of kit's from the Berlin workshop https://www.facebook.com/events/907739526048090, wasn't there, a friend brought them for me.

I have difficulties figuring the resistor values for the board.

I use this PDF https://github.com/8BitMixtape/8Bit-Mixtape-NEO/blob/master/boards/8Bit-Mixtape-NEO_v1/8BitMixtapeNEO_v11.pdf.

Looks like I have completely different values in my kit then stated on the schematics.

Help appreciated :)

Here is what I got:

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

dusjagr, 2017-09-18:
hi morris,

don't worry, you got the right parts!

first thing is how to read the codes:

the last digit is the number of 0s and the first 3 (or 2) the value.
soooo...
2202 means 220 and then 2 more zeros -> 22000 Ohm -> 22 kOhm
1001 means 1 kOhm
3300 means 330 Ohm and no zeroes at all -> 330Ohm (yes the schema says
470Ohm, but i changed...)

your link is ancient...

we have started to document in more detail on how to solder the board:
http://wiki.8bitmixtape.cc/#/0_0-Soldering-Instruction
or download the pdf:
https://github.com/8BitMixtape/8BitmixtapeNEO_ShenzhenReady/blob/master/8BitMixtapeNEO_PartsPlacement_V02.pdf

i hope that helps!

and good luck.

greets,
marc

PS: we have this fbook group for general discussion around the mixtape
https://www.facebook.com/groups/498008960391215/

and this ggroup for developers or other geeks:
https://groups.google.com/forum/#!forum/centerforalternativecoconutresearch

On Mon, Sep 18, 2017 at 8:33 AM, Morris Winkler <notifications@github.com>
wrote:

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

--
*******************************************************
!!NOTICE: new phone nr:  tel: +41 77 9930877
*******************************************************
//////dusjagr labs/////////////////////////////////////////
Dr. Marc Dusseiller
Schöneggstr. 34 | CH-8004 Zürich | tel: +41 77 9930877 | skype: dusjagr
www.dusseiller.ch/labs
//////////////////////////////////////////////////////////////////
SGMK | Schweizerische Gesellschaft für Mechatronische Kunst
Postfach 2161 | CH-8031 Zürich
www.mechatronicart.ch
//////////////////////////////////////////////////////////////////
hackteria | Open Source Biological Art
www.hackteria.org
//////////////////////////////////////////////////////////////////

morriswinkler-simplesurance, 2017-09-18:
Thanks

morriswinkler, 2017-09-19:
Ok, I think I still have an issue, or I misunderstood something.

But I count 13 Resistors on the assembly instructions, and I got 11.

I think there are 2 missing or are there some that you leave out?

dusjagr, 2017-09-19:
hi morris.

i hope not... but there might be a chance.
there also should be the 4,7kOhm, numbers 4701.

i am sorry if that one isnt in th ekit, fell out, or was swallowed by the
spaghetti monster.

good news. it's not really a crucial part, nor is it expensive. maybe
around 2 cents.
i could add a few to kasia's luggage, she'll be back in berlin in approx 10
day.

for the moment, as i said it's not a crucial part, you can just bridge this
reesistor with a wire.
http://wiki.8bitmixtape.cc/#/2_1-8Bit-Mixtape-NEO
it's part of the voltage divider in the potentiometers. so it will only
change the range of the parameters to "turn the knobs".

greetings,
marc

On Tue, Sep 19, 2017 at 8:41 AM, Morris Winkler <notifications@github.com>
wrote:

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

--
*******************************************************
!!NOTICE: new phone nr:  tel: +41 77 9930877
*******************************************************
//////dusjagr labs/////////////////////////////////////////
Dr. Marc Dusseiller
Schöneggstr. 34 | CH-8004 Zürich | tel: +41 77 9930877 | skype: dusjagr
www.dusseiller.ch/labs
//////////////////////////////////////////////////////////////////
SGMK | Schweizerische Gesellschaft für Mechatronische Kunst
Postfach 2161 | CH-8031 Zürich
www.mechatronicart.ch
//////////////////////////////////////////////////////////////////
hackteria | Open Source Biological Art
www.hackteria.org
//////////////////////////////////////////////////////////////////

Closed 2018-01-17.

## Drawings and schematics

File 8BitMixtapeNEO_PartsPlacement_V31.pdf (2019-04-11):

# Parts Placement - Complete

C1

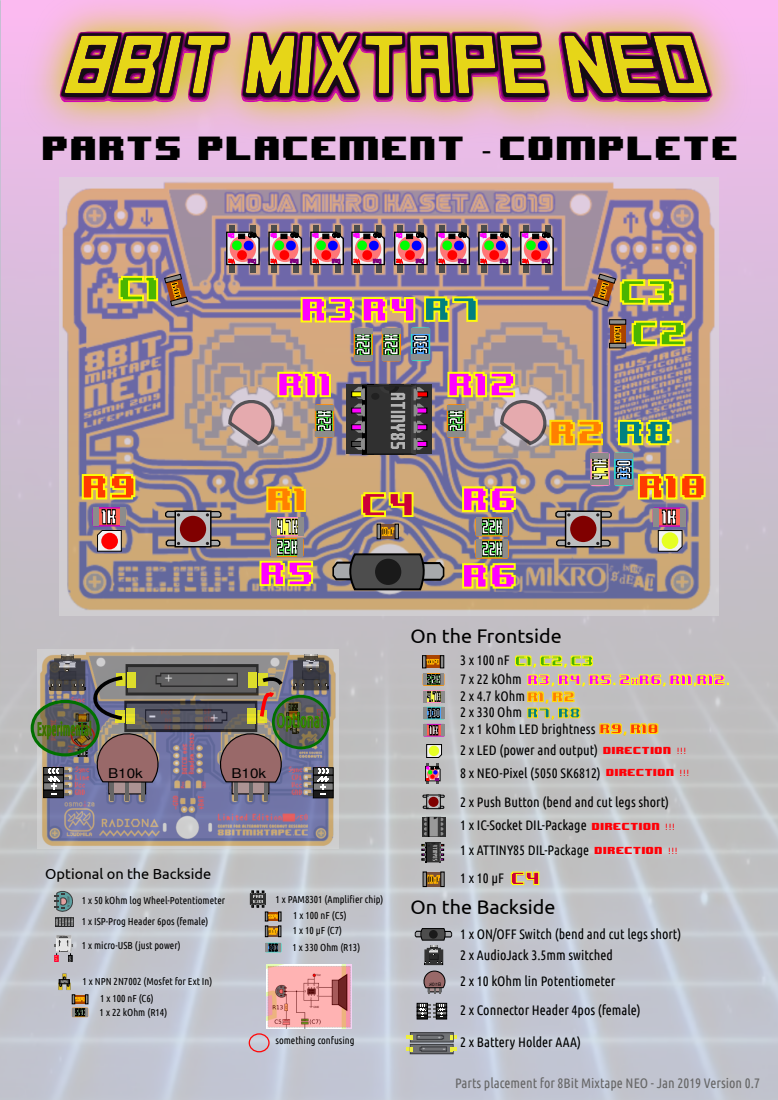
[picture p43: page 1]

7 x 22 kOhm
2 x 4.7 kOhm
2 x 330 Ohm
2 x 1 kOhm LED brightness
2 x LED (power and output)
8 x NEO-Pixel (5050 SK6812)
2 x Push Button (bend and cut legs short)
1 x IC-Socket DIL-Package
1 x ATTINY85 DIL-Package
On the Backside

Optional on the Backside

1 x 50 kOhm log Wheel-Potentiometer
1 x ISP-Prog Header 6pos (female)

MISO PB1
1 x micro-USB (just power)

1 x ON/OFF Switch (bend and cut legs short)
2 x AudioJack 3.5mm switched
2 x 10 kOhm lin Potentiometer
2 x Connector Header 4pos (female)

Vcc
1 x NPN 2N7002 (Mosfet for Ext In)

Parts placement for 8Bit Mixtape NEO - Jan 2019 Version 0.7

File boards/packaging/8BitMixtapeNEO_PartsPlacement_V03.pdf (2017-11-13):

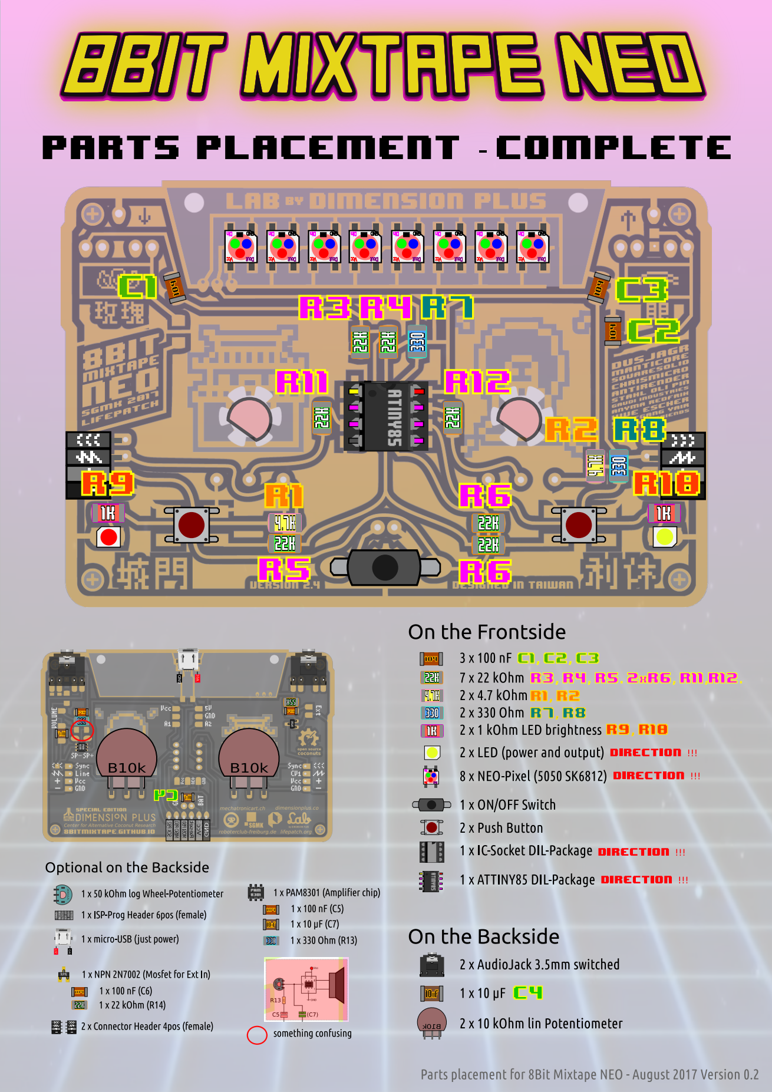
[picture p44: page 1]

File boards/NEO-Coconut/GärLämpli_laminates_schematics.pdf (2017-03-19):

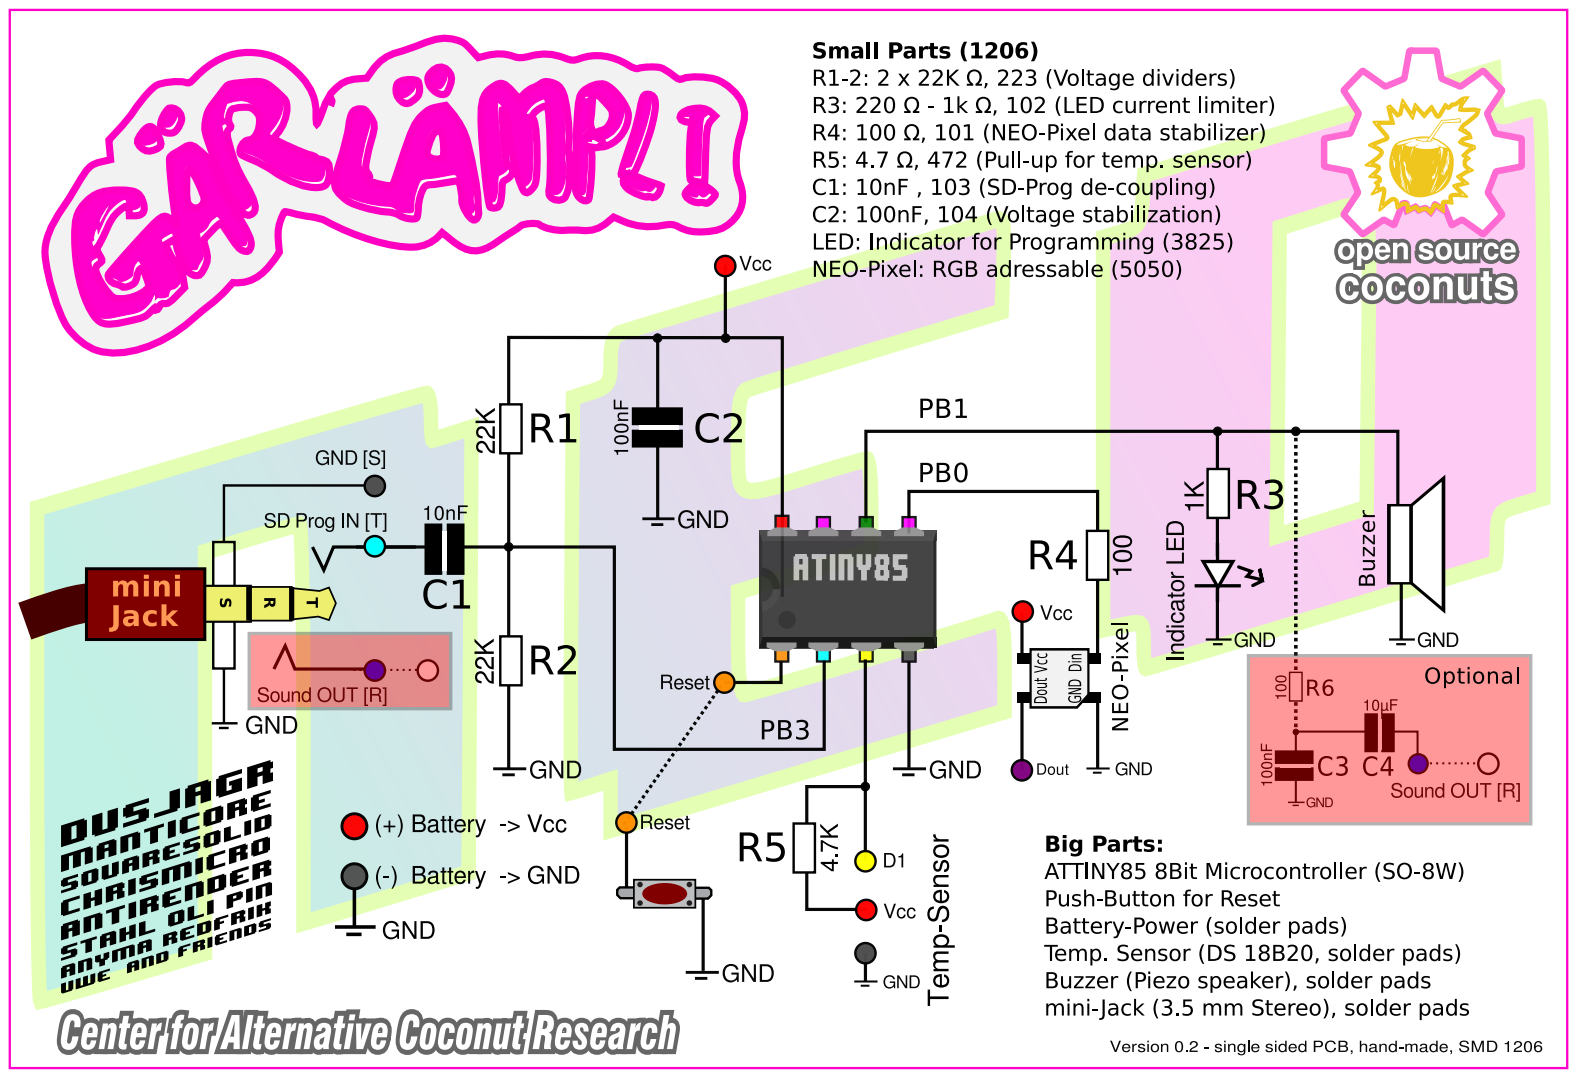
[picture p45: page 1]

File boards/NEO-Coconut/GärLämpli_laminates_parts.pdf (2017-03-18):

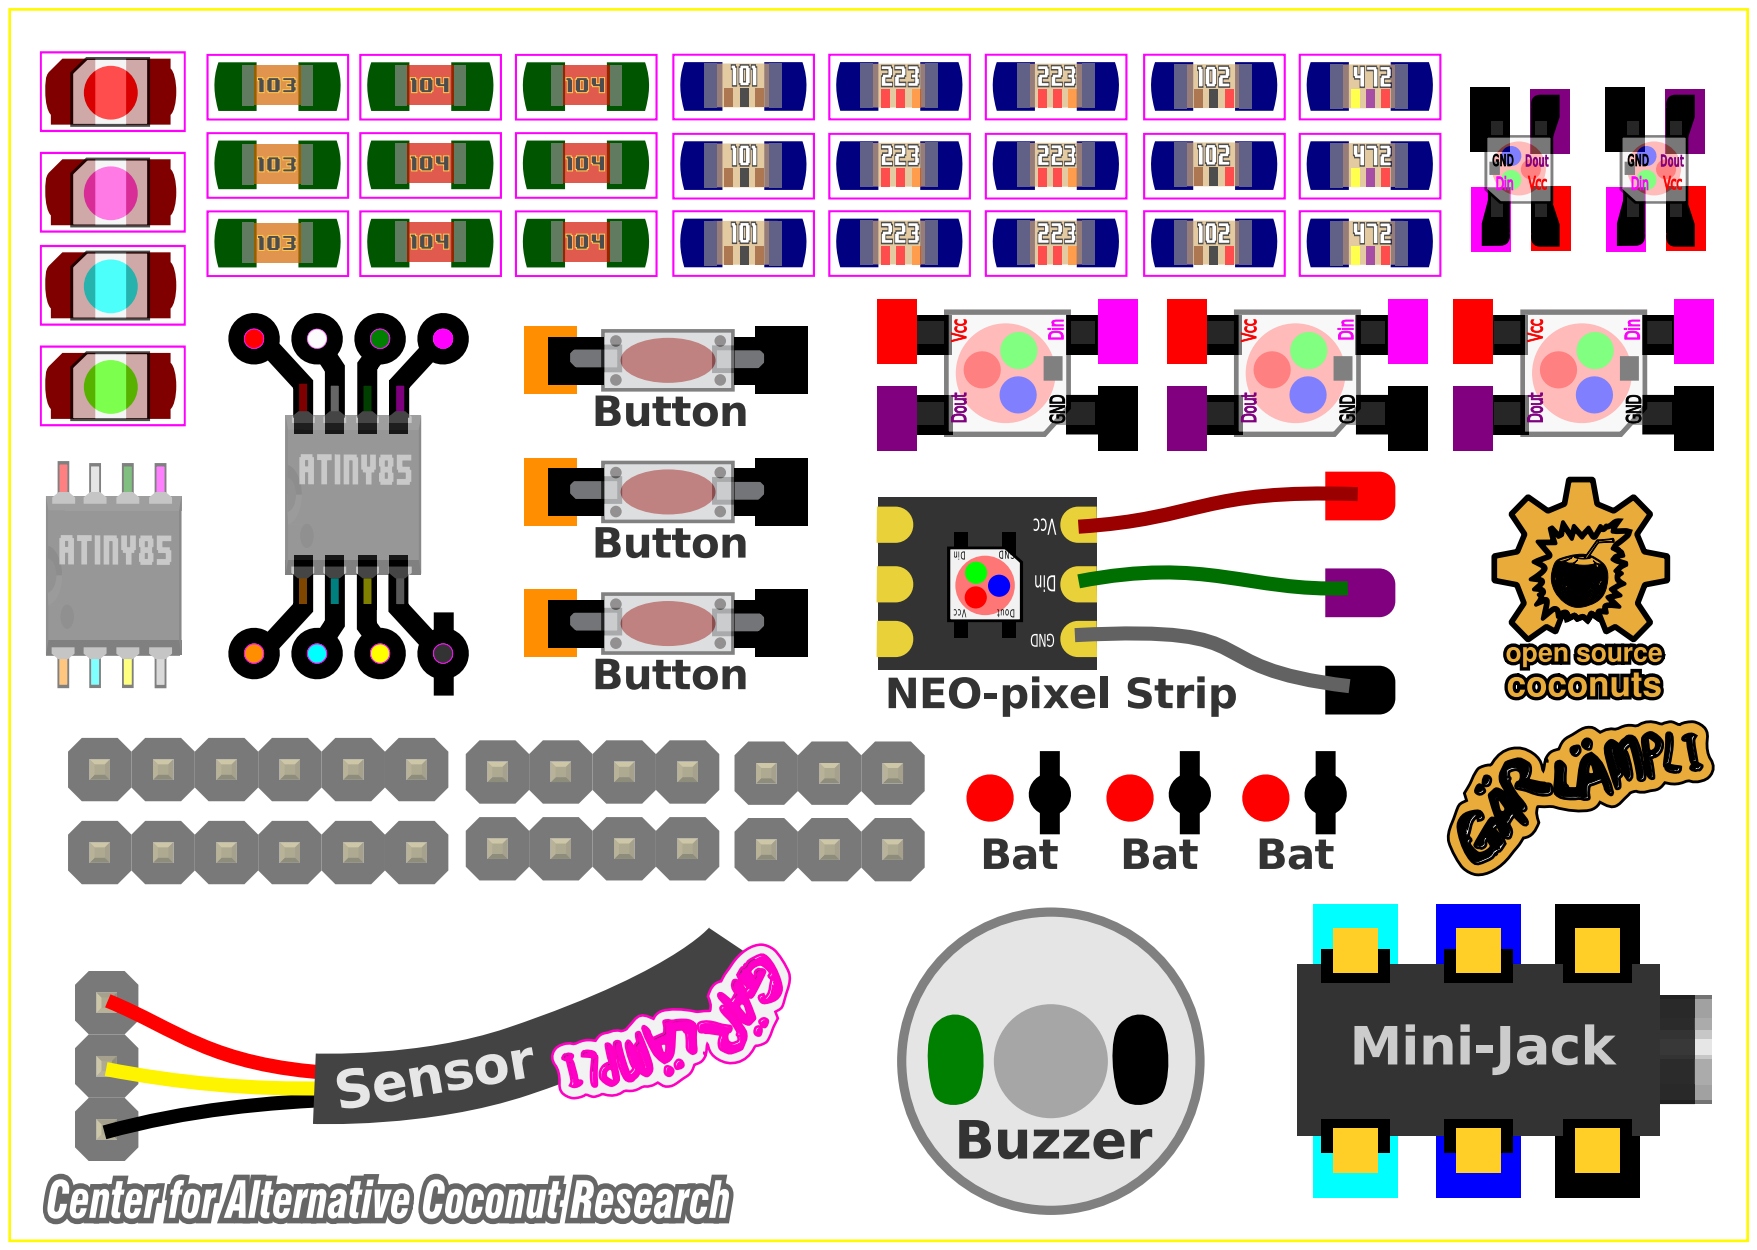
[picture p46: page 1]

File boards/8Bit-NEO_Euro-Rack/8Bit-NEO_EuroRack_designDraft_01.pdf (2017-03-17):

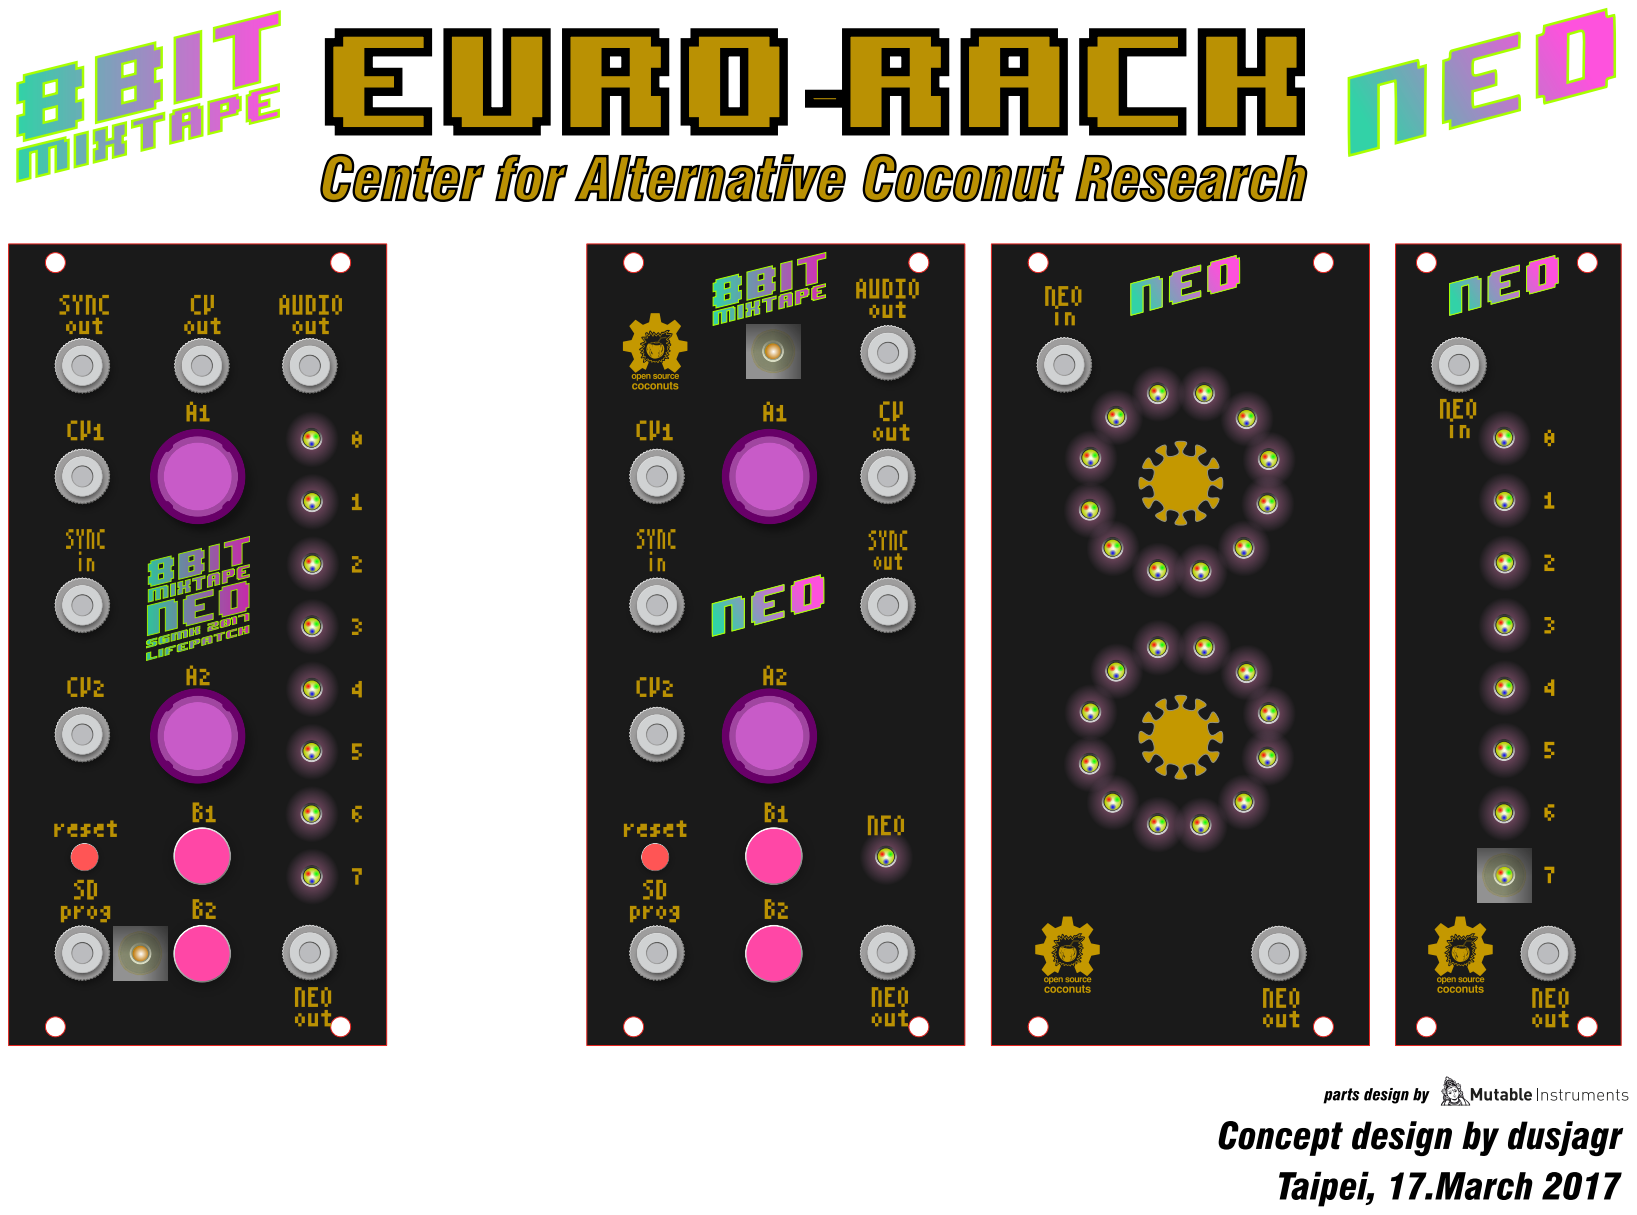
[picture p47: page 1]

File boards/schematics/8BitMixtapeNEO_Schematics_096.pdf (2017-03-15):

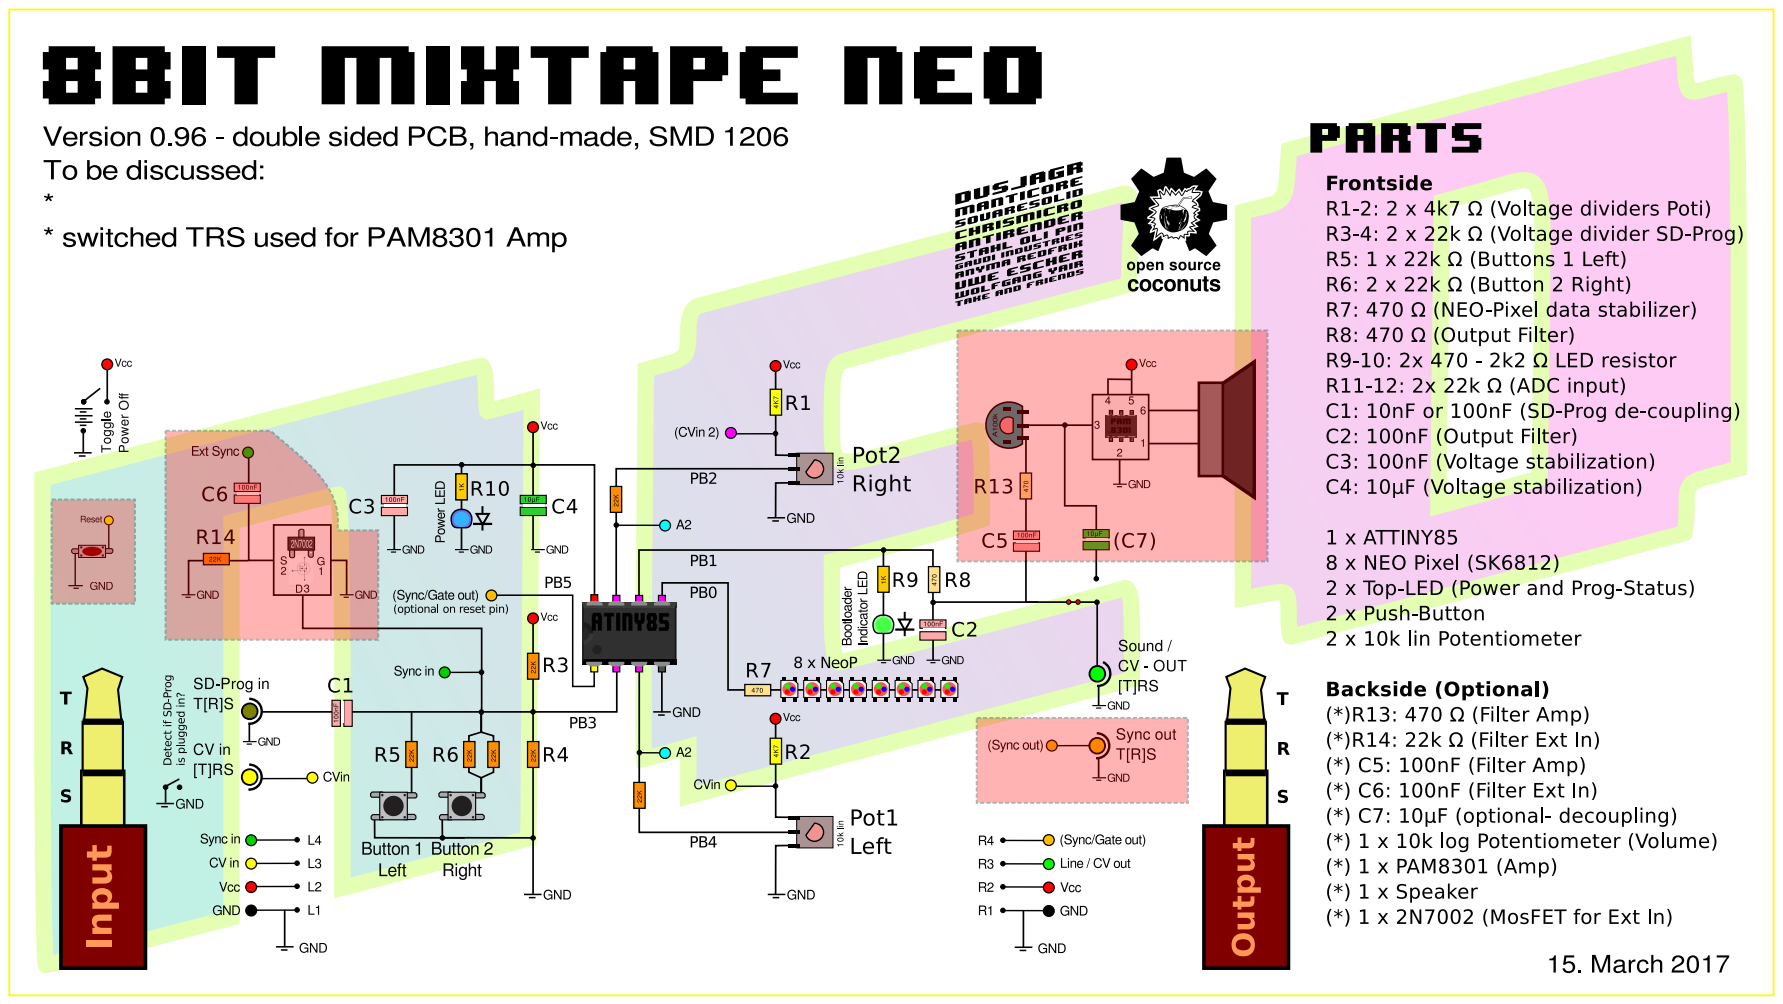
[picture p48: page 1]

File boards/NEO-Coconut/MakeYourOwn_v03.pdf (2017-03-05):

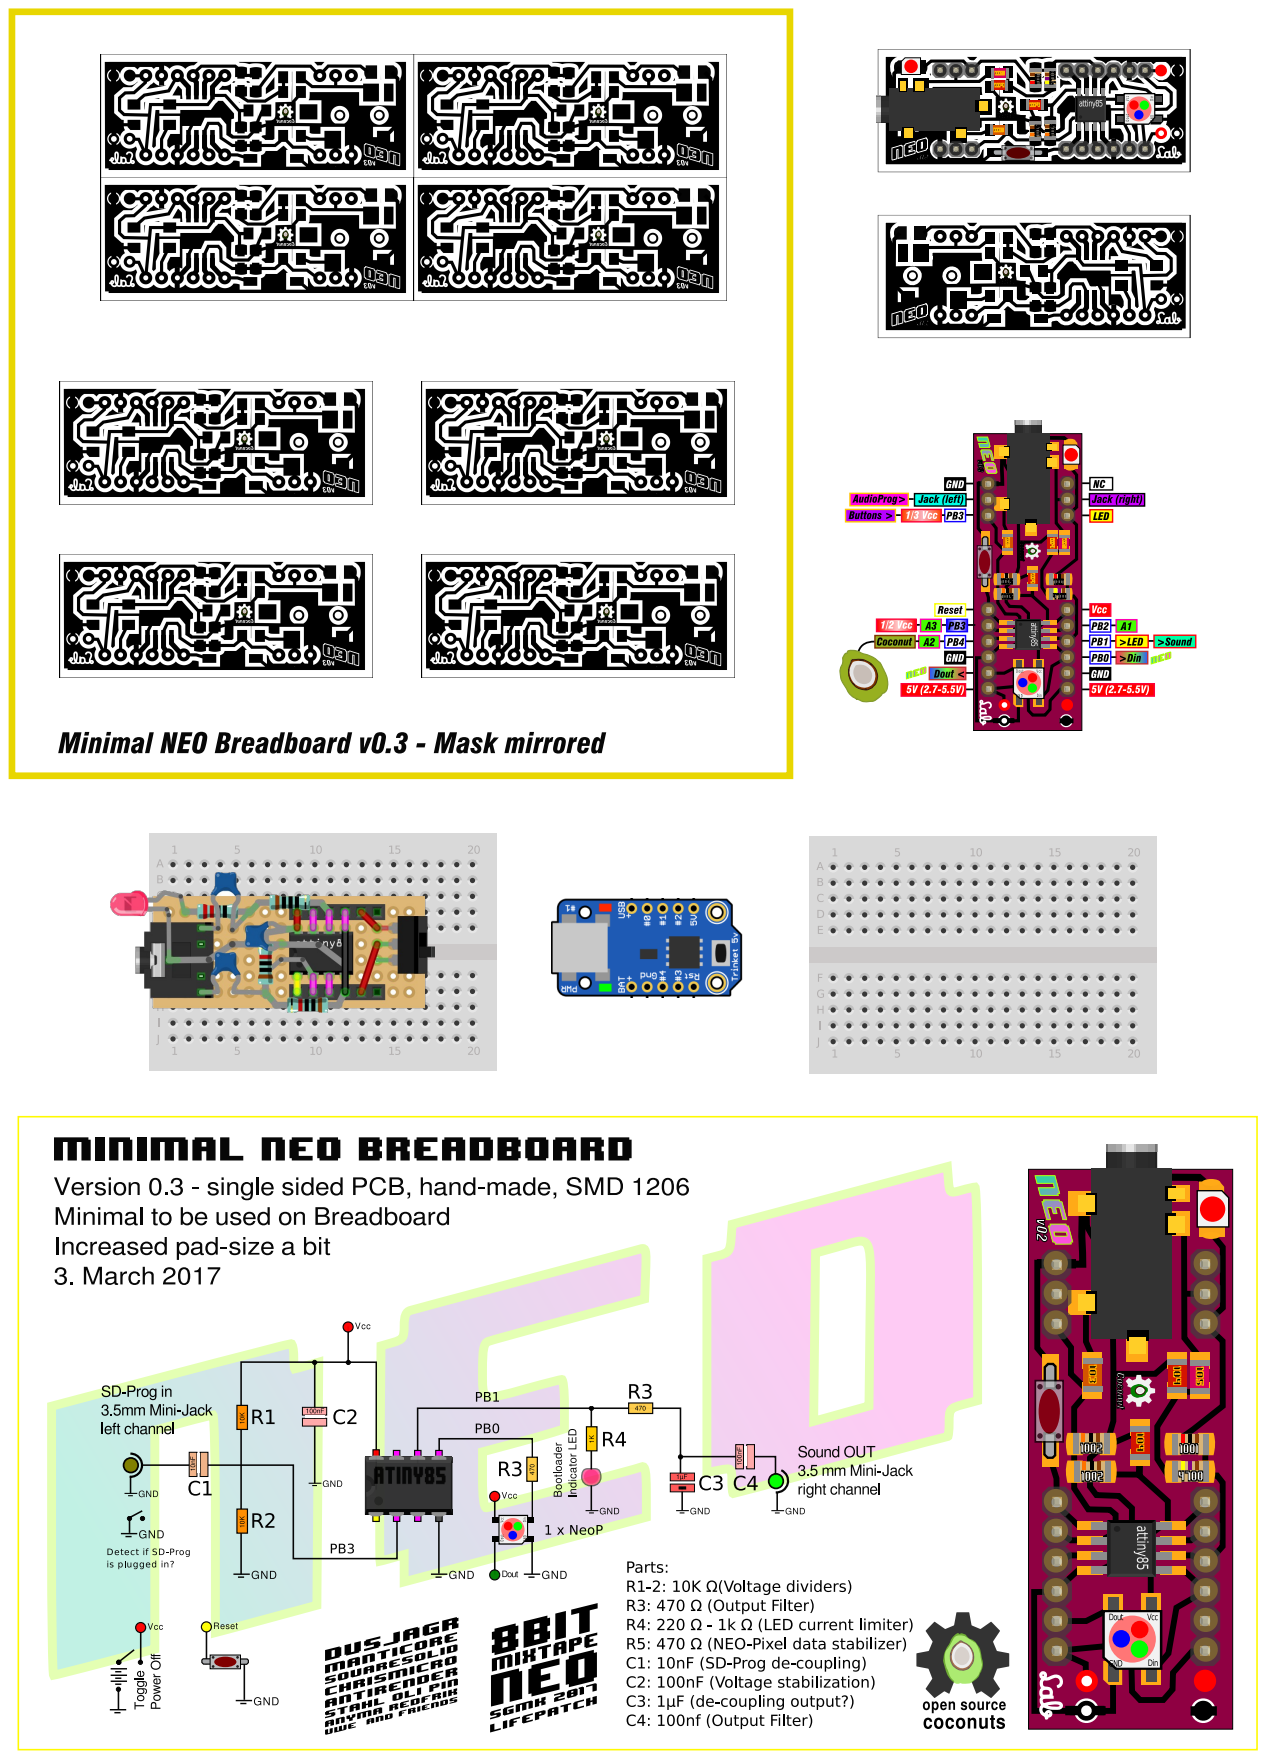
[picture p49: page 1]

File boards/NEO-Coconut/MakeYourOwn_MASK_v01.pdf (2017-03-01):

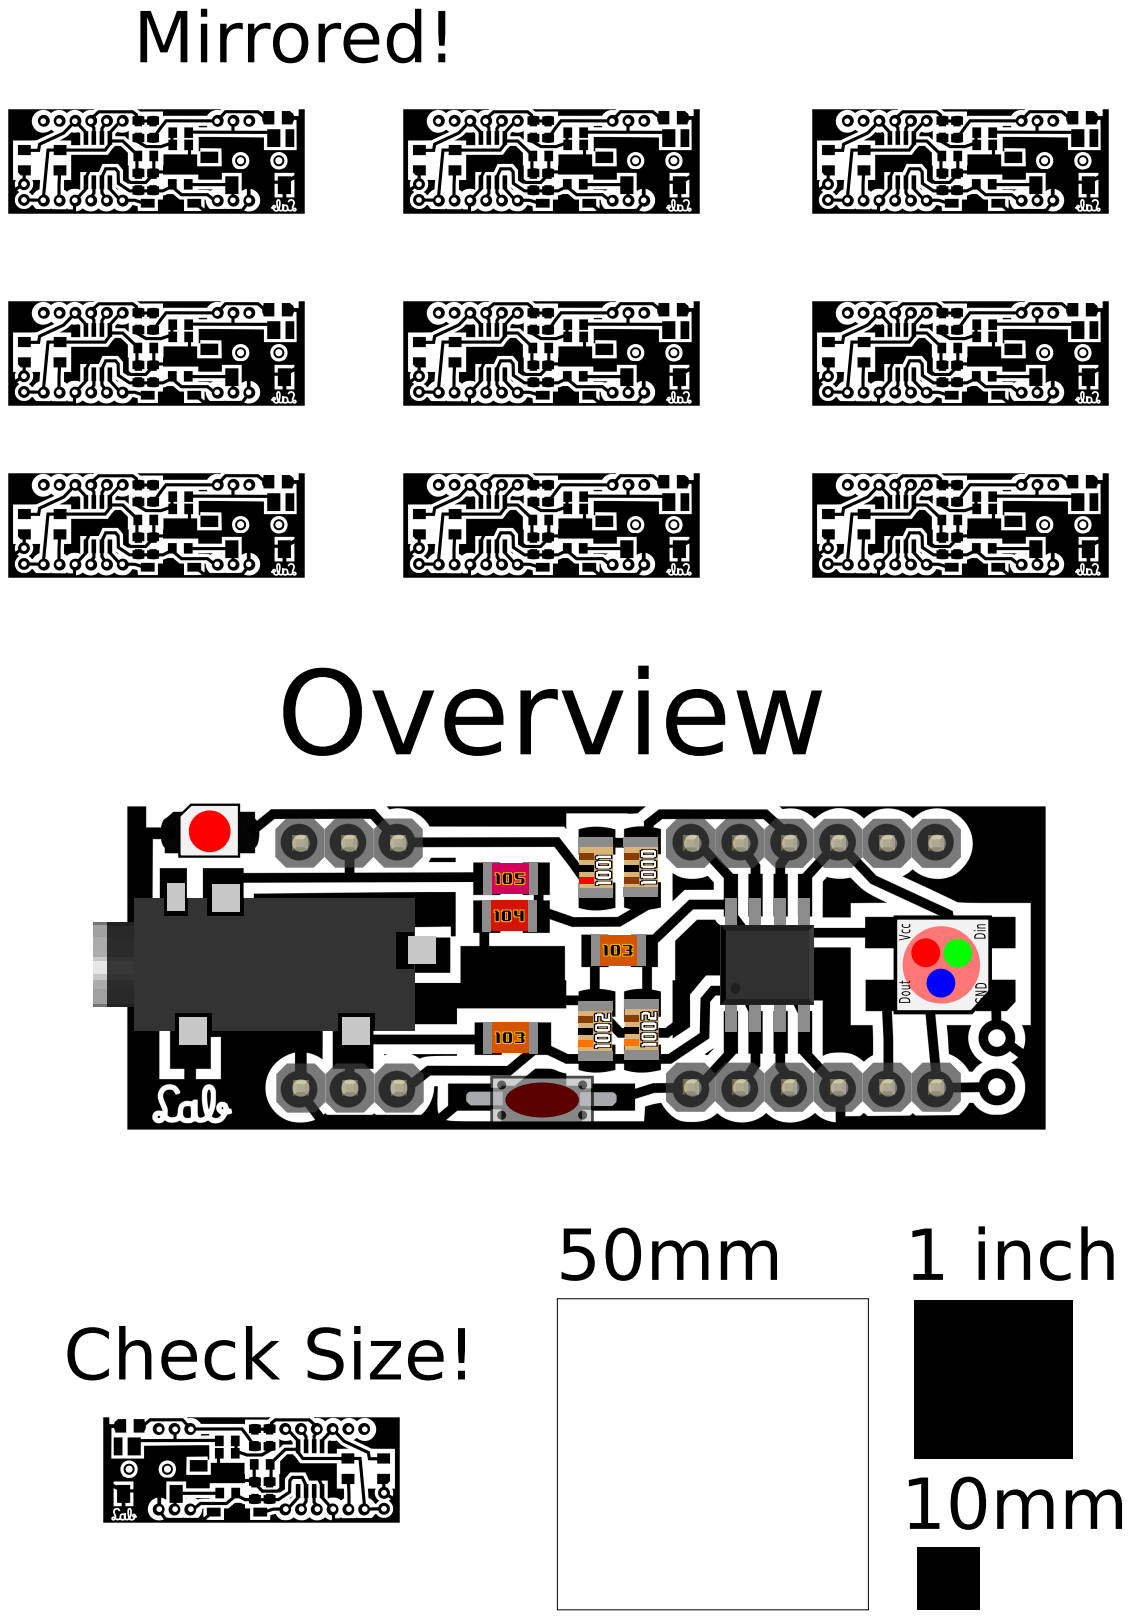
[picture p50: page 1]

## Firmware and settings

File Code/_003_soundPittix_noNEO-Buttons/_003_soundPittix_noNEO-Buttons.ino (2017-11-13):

/*************************************************************************************

  Attiny SoundPitix-VCO

  Basic sound generator for building modular mixed analog/digital
  synthesizers.

  This was originally made for the chTinySizer an little mixed analog/digital
  synthesizer with 4 ATTINY13 an one Atmega168.

  Today ( 2017 ) the sound could be improved alot by new software techncs.
  Therefore this is a more ore less historic ( 10 years ) version.


*************************************************************************************/

/*************************************************************************************

  Hardware Platform: Attiny85

                                      ATTINY85 Pins
                                      =============

                                             _______
                                            |   U   |
  DEBUGLED / SYNC-OUT             reset/PB5-|       |- VCC
  soundprog / buttons ->  D3/A3         PB3-| ATTINY|- PB2    D2/A1  <- POTI1 / CV-IN
  POTI2 / SYNC-IN ->      D4/A2         PB4-|   85  |- PB1    D1     -> PWM SOUND
                                        GND-|       |- PB0    D0     -> NEOPIXELS
                                            |_______|


*************************************************************************************/

/*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

  11.09.2007  chris, version 1.5    for ATTINY13
  13.08.2014  chris, version 1.5.1  copyright message added, code cleaned
  17.02.2017  chris, version 2.0    code reworked vor Attiny85, sound out PB1
  25.02.2017  dusjagr, version 2.1  minor edits, improve PWM mode and add some NEO-pixels
  13.3.2017 C. dusjagr, version 2.2 adapted to new schematics 0.95. different resistor values
  
  C. -H-A-B-E-R-E-R- alias chris

  Please maintain the list of authors.
  
*************************************************************************************/

#include <avr/io.h>
#include <avr/interrupt.h>
#include <stdlib.h>
#include <Adafruit_NeoPixel.h>
#ifdef __AVR__
#include <avr/power.h>
#endif

// hardware description / pin connections
#define SPEAKERPIN      1
#define NEOPIXELPIN     0

#define POTI_RIGHT     A1
#define POTI_LEFT      A2
#define BUTTONS_ADC    A3

#define NUMPIXELS      8

// hardware calibration
#define Vbutton_left   380
#define Vbutton_right  300
#define Vbutton_both   240
#define Vcc            37 // 3.7 V for LiPo
#define Vdiv           25 // measure max Voltage on Analog In

//Adafruit_NeoPixel pixels = Adafruit_NeoPixel(NUMPIXELS, NEOPIXELPIN, NEO_GRB + NEO_KHZ800);

#define INIT_ADC  ADCSRA = (1<<ADEN) | (1<<ADPS2) | (1<<ADPS1)

uint16_t adc_read(char input)
{
  // get ADC value
  uint16_t wert, temp = 0;
  uint8_t n;

  // VCC ref and ADCx
  ADMUX = (0 << REFS0) | (0x07 & input);

  // Clear ADIF and start single conversion
  ADCSRA |= (1 << ADIF) | (1 << ADSC);

  // wait for conversion done, ADIF flag active
  while (!(ADCSRA & (1 << ADIF)));

  n = ADCH; // dummy adc read

  for (n = 0; n < 4; n++)
  {
    // Clear ADIF and start single conversion
    ADCSRA |= (1 << ADIF) | (1 << ADSC);

    // wait for conversion done, ADIF flag active
    while (!(ADCSRA & (1 << ADIF)));
    // read out ADCL register
    wert = ADCL;
    // read out ADCH register
    wert += (ADCH << 8);

    temp += wert;
  }

  return (temp >> 2);
}

// sampling frequency
#define FS (37500/2) // @FCPU=9.6Mhz

uint8_t envelope = 255;
uint16_t freq_const = 440 * 65536 / FS;

#define SINUS 0
#define TRIANGLE 1
#define SAWTOOTH 2
#define RECTANGLE 3
#define NOISE 4

uint8_t wavetype = SAWTOOTH;
uint8_t RectanglePwmValue = 40;
uint16_t wert, wave, waveChange;
uint16_t adcwert;
long t = 0;
uint8_t n;
uint8_t bright = 35;
int buttonState1 = 1; 
int lastButtonState1 = 1;
int buttonState2 = 1;
int lastButtonState2 = 1;
int visuals = 1;

int8_t sinwerte[17] = {0, 12, 25, 37, 49, 60, 71, 81, 90, 98, 106, 112, 117, 122, 125, 126, 127 };

SIGNAL(TIMER1_COMPA_vect)
{
  static uint8_t x;
  static uint16_t phase1, oldphase;
  static int8_t k, flag = 0;
  static int16_t temp, temp2;
  static uint16_t noise = 0xAA;

  if (flag)
  {
    //Phase VCO
    oldphase = phase1;
    phase1 = phase1 + freq_const;

    if (wavetype == SINUS)
    {
      x = phase1 >> 10;

      if (x > 48)
      {
        x = 64 - x;
        k = -sinwerte[x];
      }
      else if (x > 32)
      {
        x = x - 32;
        k = -sinwerte[x];
      }
      else if (x > 16)
      {
        x = 32 - x;
        k = sinwerte[x];
      }
      else
      {
        k = sinwerte[x];
      }
      temp = k;
    }
    if (wavetype == TRIANGLE)
    {
      x = phase1 >> 8;
      if (x & 0x80) temp = (x ^ 0xFF);
      else temp = x;
      temp = (temp << 1) - 128;
    }

    if (wavetype == RECTANGLE)
    {
      x = phase1 >> 8;
      if (x > RectanglePwmValue)
      {
        temp = 127;
      }
      else temp = -127;
    }
    if (wavetype == SAWTOOTH)
    {
      temp = (phase1 >> 8) - 128;
    }
    if (wavetype == NOISE)
    {
      temp = noise;
      noise = noise << 1;
      temp ^= noise;
      if ( ( temp & 0x4000 ) == 0x4000 )noise |= 1;

      if ((oldphase ^ phase1) & 0x4000)
      {
        temp2 = (noise >> 6) & 0xFF;
      }
      temp = temp2;
    }
  }
  else
  {
    temp = (temp * envelope);

    OCR1A = (temp >> 8) + 128;

  }
  flag ^= 0x01;
}


uint8_t getButton()
{
  uint8_t button = 0;
  if (analogRead(BUTTONS_ADC) < Vbutton_left) button = 1;
  if (analogRead(BUTTONS_ADC) < Vbutton_right) button = 2;
  if (analogRead(BUTTONS_ADC) < Vbutton_both) button = 3;

  return button;
}

// scaled the adc of the 8BitMixTape voltage divider
// to a return value in range: 0..1023
// Use Vcc / Vdiv as measured on your hardware
uint16_t analogReadScaled(uint8_t channel)
{
  uint16_t value = analogRead(channel);
  value = value * Vcc / Vdiv;
  if (value > 1023) value = 1023;
  return value;
}

int main(void)
{

  INIT_ADC;
  cli();

  // Set up Timer/Counter1 62kHz.
  TCCR1 &= ~(0x0F << CS10); // make sure bits are empty
  TCCR1 |= 1 << CS11;    // set prescaler 1/8

  // pulse width modulator A enable
  TCCR1 &= ~(1 << COM1A0);       // make sure register is empty
  TCCR1 |=   1 << COM1A1 ;       // PWM mode: clear the OC1A output line on compare match

  TCCR1 |= 1 << PWM1A;           // PWM mode

  TIMSK |= 1 << OCIE1A;          // Enable compare match interrupt for timer 1

  OCR1A = 128;                   // initialize PWM to 50% mean value

  DDRB |= 1 << PB1; // PWM pin as output

  sei();

  // Ports
  PORTB = (1 << PORTB2) | (1 << PORTB3); // Pullup

  #if defined (__AVR_ATtiny85__)
  if (F_CPU == 16000000) clock_prescale_set(clock_div_1); //what is this?
  #endif
  
  while (1)
  {
    uint8_t x = getButton();
    
    if (x == 0) {
      buttonState1 = HIGH;
      buttonState2 = HIGH;
    }
    
    if (x == 2) {
      buttonState2 = LOW;
      buttonState1 = HIGH;
      bright = analogReadScaled(POTI_RIGHT)>>3; 
    }
    
    if (buttonState2 != lastButtonState2 && buttonState2 == HIGH) {
      
            
    }

    if (x == 1) {
      buttonState1 = LOW;
    }
    
    if (buttonState1 != lastButtonState1 && buttonState1 == HIGH) {
    // if the state has changed, increment the counter
      visuals++; 
      if (visuals > 1) {
        visuals = 0;
        
      } 
    }

  lastButtonState1 = buttonState1;
  lastButtonState2 = buttonState2;
    
    adcwert = analogReadScaled(POTI_LEFT);
    adcwert = adcwert;
    freq_const = adcwert * 65536 / FS / 1;
    /* LFO switch
        if (PINB & (1 << PINB1))
        {
          //TCCR0B = (1 << CS00); // VCO
          TCCR1 &= ~(0x0F << CS10); // make sure bits are empty
          TCCR1 |= 1 << CS13;    // set prescaler 1/8
        }
        else
        {
          //freq_const=adcwert*65536/FS/4; // LFO ( 1/10 Frequency )
          //TCCR0B = (1 << CS01) ; // 1/8 prescaling,
          TCCR1 &= ~(0x0F << CS10); // make sure bits are empty
          TCCR1 |= 1 << CS13;    // set prescaler
          TCCR1 |= 1 << CS12;    // set prescaler
          freq_const = adcwert;
        }
    */
    //envelope= adc_read(VOLUME_CONTROL)>>2;
    envelope = 255;
    wert =  2 * (255 - (analogReadScaled(POTI_RIGHT)>>2));
    if (wert > 255)wert = 255;

    if(wert<=10) {wave=NOISE;}  
    if(wert>10) {wave=RECTANGLE;RectanglePwmValue=0x02;}
    if(wert>55) {wave=RECTANGLE;RectanglePwmValue=0x04;}
    if(wert>60) {wave=RECTANGLE;RectanglePwmValue=0x06;}
    if(wert>65) {wave=RECTANGLE;RectanglePwmValue=0x09;}
    if(wert>70) {wave=RECTANGLE;RectanglePwmValue=0x12;}
    if(wert>75) {wave=RECTANGLE;RectanglePwmValue=0x15;}
    if(wert>80) {wave=RECTANGLE;RectanglePwmValue=0x20;}
    if(wert>85) {wave=RECTANGLE;RectanglePwmValue=0x26;}
    if(wert>90) {wave=RECTANGLE;RectanglePwmValue=0x32;}      
    if(wert>95) {wave=RECTANGLE;RectanglePwmValue=0x40;}      
    if(wert>100) {wave=RECTANGLE;RectanglePwmValue=0x50;}
    if(wert>105) {wave=RECTANGLE;RectanglePwmValue=0x64;}  
    if(wert>110) {wave=RECTANGLE;RectanglePwmValue=0x80;}  
    if(wert>150) wave=SAWTOOTH; 
    if(wert>170) wave=TRIANGLE;
    if(wert>200) wave=SINUS;

    wavetype = wave;
    
    waveChange = wave;
      
  }
}

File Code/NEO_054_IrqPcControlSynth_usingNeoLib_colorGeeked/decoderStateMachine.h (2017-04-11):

#ifdef __cplusplus
extern "C"
{
#endif

#ifndef __DECODERSTATEMACHINE__
#define __DECODERSTATEMACHINE__

	#include "stdint.h"

#define INPUTAUDIOPIN (1<<PB3) //
#define PINVALUE (PINB&INPUTAUDIOPIN)
#define INITAUDIOPORT {DDRB&=~INPUTAUDIOPIN;} // audio pin is input

#define PINLOW (PINVALUE==0)
#define PINHIGH (!PINLOW)

#define LEDPORT    ( 1<<PB0 ); //PB1 pin 6 Attiny85
#define INITLED    { DDRB|=LEDPORT; }

#define LEDON      { PORTB|=LEDPORT;}
#define LEDOFF     { PORTB&=~LEDPORT;}
#define TOGGLELED  { PORTB^=LEDPORT;}

	#define FRAMESIZE 2 // number of bytes
	#define SYNCCOUNTER 9 // minimum number of bits which should have equal duration

	#define VOID 0
	#define START 1

	// state machine 1 state definitons
	#define M1_READY   0
	#define M1_PINLOW  1	// pin low state from machine 1
	#define M1_PINHIGH 2	// pin high state from machine 1

	typedef uint8_t state_t;
	typedef uint8_t command_t;

	enum bitState { SENDERBITREADY, BITREADY,BITSTART,BITEND };
	extern uint8_t BitValue;

	#define BITOK 0
	#define BITTIMEOUT 1
	#define TOSHORT 2

	extern uint8_t BitError;

	state_t BrEstimationStateMachine(command_t command);
	enum bitState highBitReceived_S(void);

	#define BYTEREADY 0
	#define WAITFORSTARTBIT 1
	#define RECEIVEBITS 2

	extern uint8_t ReceiverData;
	uint8_t receiveByte_S(void);

	#define FRAMEOK 0
	#define FRAMETIMEOUT 1

	#define FRAMEREADY          0
	#define BITRATEESTIMATION   1
	#define RECEIVEBYTES        2
	#define DATARECEIVED        3

  extern volatile uint8_t FrameData[FRAMESIZE];
  extern uint16_t DecoderData;  
  extern uint8_t FrameError;

  void decoderBegin();
  uint8_t isDataAvailable();
	uint8_t receiveFrame_S(void);

#endif // __DECODERSTATEMACHINE__

#ifdef __cplusplus
}
#endif

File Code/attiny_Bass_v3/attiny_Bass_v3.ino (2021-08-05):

// ######################## Clock 16 Mhz intern ############################################

#include <avr/pgmspace.h>
#include "neolib.h"

uint8_t sync = 0;
uint8_t wave = 1;

bool full = true;

uint8_t uSteps = 192;                                // microsteps in one octave
unsigned int Acc = 255;
unsigned int Acc2 = 255;
//const uint8_t vol = 255;
unsigned int note = 214;
unsigned int baseNote = 288;
unsigned int note2, type;
bool gateOpen;

//


const unsigned int tunes1345steps[] PROGMEM = {
  54, 54, 54, 54, 54, 55, 55, 55, 55, 55, 56, 56, 56, 56, 56, 57,   // tempered 12 tune steps on left column
  57, 57, 57, 57, 58, 58, 58, 58, 58, 59, 59, 59, 59, 59, 60, 60,    // others are used as microsteps for detune
  60, 60, 61, 61, 61, 61, 61, 62, 62, 62, 62, 63, 63, 63, 63, 63,
  64, 64, 64, 64, 65, 65, 65, 65, 66, 66, 66, 66, 67, 67, 67, 67,
  68, 68, 68, 68, 68, 69, 69, 69, 69, 70, 70, 70, 70, 71, 71, 71,
  72, 72, 72, 72, 73, 73, 73, 73, 74, 74, 74, 74, 75, 75, 75, 76,
  76, 76, 76, 77, 77, 77, 77, 78, 78, 78, 79, 79, 79, 79, 80, 80,
  80, 81, 81, 81, 81, 82, 82, 82, 83, 83, 83, 84, 84, 84, 84, 85,
  85, 85, 86, 86, 86, 87, 87, 87, 88, 88, 88, 89, 89, 89, 89, 90,
  90, 90, 91, 91, 91, 92, 92, 92, 93, 93, 93, 94, 94, 94, 95, 95,
  95, 96, 96, 97, 97, 97, 98, 98, 98, 99, 99, 99, 100, 100, 100, 101,
  101, 102, 102, 102, 103, 103, 103, 104, 104, 104, 105, 105, 106, 106, 106, 107,   // here the first octave ends
  107, 108, 108, 108, 109, 109, 110, 110, 110, 111, 111, 112, 112, 112, 113, 113,
  114, 114, 114, 115, 115, 116, 116, 116, 117, 117, 118, 118, 119, 119, 119, 120,
  120, 121, 121, 122, 122, 122, 123, 123, 124, 124, 125, 125, 126, 126, 127, 127,
  127, 128, 128, 129, 129, 130, 130, 131, 131, 132, 132, 133, 133, 134, 134, 135,
  135, 136, 136, 136, 137, 137, 138, 138, 139, 139, 140, 140, 141, 142, 142, 143,
  143, 144, 144, 145, 145, 146, 146, 147, 147, 148, 148, 149, 149, 150, 150, 151,
  152, 152, 153, 153, 154, 154, 155, 155, 156, 157, 157, 158, 158, 159, 159, 160,
  161, 161, 162, 162, 163, 163, 164, 165, 165, 166, 166, 167, 168, 168, 169, 169,
  170, 171, 171, 172, 173, 173, 174, 174, 175, 176, 176, 177, 178, 178, 179, 180,
  180, 181, 182, 182, 183, 184, 184, 185, 186, 186, 187, 188, 188, 189, 190, 190,
  191, 192, 192, 193, 194, 194, 195, 196, 197, 197, 198, 199, 199, 200, 201, 202,
  202, 203, 204, 204, 205, 206, 207, 207, 208, 209, 210, 210, 211, 212, 213, 214,
  214, 215, 216, 217, 217, 218, 219, 220, 221, 221, 222, 223, 224, 225, 225, 226,
  227, 228, 229, 230, 230, 231, 232, 233, 234, 235, 235, 236, 237, 238, 239, 240,
  241, 241, 242, 243, 244, 245, 246, 247, 248, 249, 249, 250, 251, 252, 253, 254,
  255, 256, 257, 258, 259, 260, 260, 261, 262, 263, 264, 265, 266, 267, 268, 269,
  270, 271, 272, 273, 274, 275, 276, 277, 278, 279, 280, 281, 282, 283, 284, 285,
  286, 287, 288, 289, 290, 291, 292, 293, 294, 296, 297, 298, 299, 300, 301, 302,
  303, 304, 305, 306, 308, 309, 310, 311, 312, 313, 314, 315, 317, 318, 319, 320,
  321, 322, 323, 325, 326, 327, 328, 329, 331, 332, 333, 334, 335, 337, 338, 339,
  340, 341, 343, 344, 345, 346, 348, 349, 350, 351, 353, 354, 355, 357, 358, 359,
  360, 362, 363, 364, 366, 367, 368, 370, 371, 372, 374, 375, 376, 378, 379, 381,
  382, 383, 385, 386, 387, 389, 390, 392, 393, 394, 396, 397, 399, 400, 402, 403,
  405, 406, 408, 409, 410, 412, 413, 415, 416, 418, 419, 421, 423, 424, 426, 427,
  429, 430, 432, 433, 435, 436, 438, 440, 441, 443, 444, 446, 448, 449, 451, 452,
  454, 456, 457, 459, 461, 462, 464, 466, 467, 469, 471, 473, 474, 476, 478, 479,
  481, 483, 485, 486, 488, 490, 492, 493, 495, 497, 499, 501, 502, 504, 506, 508,
  510, 512, 513, 515, 517, 519, 521, 523, 525, 527, 528, 530, 532, 534, 536, 538,
  540, 542, 544, 546, 548, 550, 552, 554, 556, 558, 560, 562, 564, 566, 568, 570,
  572, 574, 576, 578, 580, 583, 585, 587, 589, 591, 593, 595, 598, 600, 602, 604,
  606, 608, 611, 613, 615, 617, 619, 622, 624, 626, 628, 631, 633, 635, 638, 640,
  642, 645, 647, 649, 652, 654, 656, 659, 661, 663, 666, 668, 671, 673, 676, 678,
  680, 683, 685, 688, 690, 693, 695, 698, 700, 703, 705, 708, 711, 713, 716, 718,
  721, 724, 726, 729, 731, 734, 737, 739, 742, 745, 747, 750, 753, 756, 758, 761,
  764, 767, 769, 772, 775, 778, 780, 783, 786, 789, 792, 795, 798, 800, 803, 806,
  809, 812, 815, 818, 821, 824, 827, 830, 833, 836, 839, 842, 845, 848, 851, 854,
  857, 860, 864, 867, 870, 873, 876, 879, 882, 886, 889, 892, 895, 898, 902, 905,
  908, 912, 915, 918, 921, 925, 928, 932, 935, 938, 942, 945, 948, 952, 955, 959,
  962, 966, 969, 973, 976, 980, 983, 987, 990, 994, 998, 1001, 1005, 1009, 1012, 1016,
  1020, 1023, 1027, 1031, 1034, 1038, 1042, 1046, 1049, 1053, 1057, 1061, 1065, 1068, 1072, 1076,
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
};

const byte sine256[] PROGMEM = { // sine wavetable
  0, 0, 0, 0, 0, 0, 1, 1, 1, 2, 2, 3, 4, 5, 5, 6, 7, 9, 10, 11, 12, 14, 15, 17, 18, 20, 21, 23, 25, 27, 29, 31, 33, 35, 37, 40, 42, 44, 47, 49, 52, 54, 57, 59, 62, 65, 67, 70, 73, 76, 79, 82, 85, 88, 90, 93, 97, 100, 103, 106, 109, 112, 115, 118, 121, 124, 128,
  128, 131, 134, 137, 140, 143, 146, 149, 152, 155, 158, 162, 165, 167, 170, 173, 176, 179, 182, 185, 188, 190, 193, 196, 198, 201, 203, 206, 208, 211, 213, 215, 218, 220, 222, 224, 226, 228, 230, 232, 234, 235, 237, 238, 240, 241, 243, 244, 245, 246,
  248, 249, 250, 250, 251, 252, 253, 253, 254, 254, 254, 255, 255, 255, 255, 255, 255, 255, 254, 254, 254, 253, 253, 252, 251, 250, 250, 249, 248, 246, 245, 244, 243, 241, 240, 238, 237, 235, 234, 232, 230, 228, 226, 224, 222, 220, 218, 215, 213, 211,
  208, 206, 203, 201, 198, 196, 193, 190, 188, 185, 182, 179, 176, 173, 170, 167, 165, 162, 158, 155, 152, 149, 146, 143, 140, 137, 134, 131, 128, 124, 121, 118, 115, 112, 109, 106, 103, 100, 97, 93, 90, 88, 85, 82, 79, 76, 73, 70, 67, 65,
  62, 59, 57, 54, 52, 49, 47, 44, 42, 40, 37, 35, 33, 31, 29, 27, 25, 23, 21, 20, 18, 17, 15, 14, 12, 11, 10, 9, 7, 6, 5, 5, 4, 3, 2, 2, 1, 1, 1, 0
};

void setup() {
  
  OSCCAL += 3;                            // Oscillator calibration

  // Enable 64 MHz PLL and use as source for Timer1
  PLLCSR = 1 << PCKE | 1 << PLLE;

  // Set up Timer/Counter1 for PWM output
  TIMSK = 0;                                          // Timer interrupts OFF
  TCCR1 = 1 << PWM1A | 2 << COM1A0 | 1 << CS10;       // PWM OCR1A, clear on match, 1:1 prescale
  pinMode(1, OUTPUT);                                 // Enable PWM output pin

  // Set up Timer/Counter0 for interrupt to output samples.
  TCCR0A = 3 << WGM00;                                // Fast PWM
  TCCR0B = 1 << WGM02 | 2 << CS00;                    // 1/8 prescale
  TIMSK = 1 << OCIE0A;                                // Enable compare match, disable overflow
  OCR0A = 199;                                         // Divide by 400
  pinMode(0, OUTPUT);
  neobegin();
  //setColorAllPixel(colorWheel(220));
  //pixels.show();
}
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

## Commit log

2017-02-05 Updated schematics, uwe's design, numbering
2017-02-25 corrected all files and .ino
    [_003_soundPittix_NEO-Buttons.ino]
2017-03-06 Schematics NEO v1.1 added
2017-03-08 Uwe's MegaUberEverything Schematics
2017-03-13 New MASK for DIY board 1.5 and 1.6
2017-03-13 New MASK for DIY board 1.6
2017-03-13 correctly mirrored MASK for DIY board 1.6
2017-03-14 upadting schematics
2017-03-14 updated the Schematics v0.96
2017-03-16 New board added DIMI-8 hon. Kurenniemi
2017-03-17 scaled DIMI-8 to bigger board. complete redesign
2017-03-17 Gär Lämply diy-CAD boards
2017-03-18 Gär Lämply diy-CAD grid
2017-03-18 diy-CAD Version 0.2 laminates
2017-03-19 fixed size of laminates schematics
    [DS18x20_Temperature_NEO.ino]
2017-03-20 fixed .wav files location
    [NEO_022_FamilyMart.ino, NEO_8Pixel-OneLiners.ino]
2017-03-31 some new files for dimi
    [8BitMixtape_NEO_v20_cuts.dxf]
2017-04-11 DIMI & GärLämpli Boxology
    [DIMI_chistli.dxf, DIMI_chistli.scad, Unagi_chistli.scad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]
2017-04-11 colorGeeked irq-synth
    [8Bit_Mixtape_NEO_productionReady.kicad_pcb, 8Bit_Mixtape_NEO_productionReady.sch, DIMI-8_interface.kicad_pcb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]
2017-04-18 added new MASK 2.1
    [Unagi_chistli.scad]
2017-06-10 added cocoCat codes
    [DIMI_chistli.scad, DIMI_chistli_anyma_10.dxf, DIMI_chistli_anyma_10.scad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]
2017-06-15 adding 3d files for MixTape Case
    [3D_mixTape_Cover_v03_16.stl, 3D_mixTape_Frame_v03_95.stl, 3D_mixTape_FullCase_v03_95.stl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]
2017-06-18 adding model with parts
    [3D_mixTape_ModelParts.stl, 3D_mixTape_Rahmli.scad]
2017-06-22 :punch: added usb charger case
    [3D_mixTape_FullCase_USB.stl, 3D_mixTape_Rahmli.scad, mixtape_case_3D_MainCase_USB.dxf]
2017-06-22 optimized USB version
    [3D_mixTape_FullCase_USB2.stl]
2017-07-21 added batch1 Gerber and Kicad files
    [8BitMixtapeNEO_HK-B.Cu.gbr, 8BitMixtapeNEO_HK-B.Mask.gbr, 8BitMixtapeNEO_HK-B.SilkS.gbr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]
2017-11-13 adding packaging files
    [2D_mixTape_Rahmli.scad, 3D_mixTape_FullCase_v05_100.stl, 3D_mixTape_FullCase_v06_100.stl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]
2017-11-13 adding newest design and gerber
    [8BitMixtapeNEO_Berlin-B.Cu.gbr, 8BitMixtapeNEO_Berlin-B.Mask.gbr, 8BitMixtapeNEO_Berlin-B.SilkS.gbr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]
2017-11-21 version 1.1, etched but too bigg pads and headphone jack footprint change
2018-01-22 add openscad etc
    [3D_mixTape_Cover_v03_16.stl, 3D_mixTape_Frame_v03_95.stl, 3D_mixTape_FullCase_USB.stl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]
2018-12-08 thin out the walls to fit batteries.
    [2D_mixTape_Rahmli.scad]
2018-12-10 updated 3d-printabel case
    [2D_mixTape_Rahmli_bat.scad, 2D_mixTape_Rahmli_bat.stl, 2D_mixTape_Rahmli_bat_thin.stl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]
2018-12-10 new 3d-printable case
    [invite_forum.csv]
2018-12-10 optimizing 3d case
    [2D_mixTape_Rahmli.scad, 2D_mixTape_Rahmli_bat.scad, 2D_mixTape_Rahmli_bat.stl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]
2018-12-10 clean up 3d printing files
    [3D_MixTape_FullCase_VerDez18_03.stl]
2019-04-11 new 3d files
    [MixTape_Case_VerApril19_10.scad, MixTape_Case_VerMar19_05.scad, MixTape_Case_VerMar19_05.stl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]
2021-08-05 sample hold
    [BlinkeShit_Case.stl, FlexiTiny_Case.scad, FlexiTiny_Case.stl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]

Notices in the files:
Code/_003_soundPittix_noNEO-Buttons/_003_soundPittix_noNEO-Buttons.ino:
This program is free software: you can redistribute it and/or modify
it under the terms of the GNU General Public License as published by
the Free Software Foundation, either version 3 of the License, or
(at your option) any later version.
